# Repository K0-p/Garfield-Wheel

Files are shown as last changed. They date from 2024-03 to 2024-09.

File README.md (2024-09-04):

# Garfield Wheel

### HID-compliant (and Garfield-themed) game controller with embedded button mapping firmware and gyroscope controls
###### *Designed to run on the TM4C*

Developed by Gabriel Moore and Calvin Heischman

[Spring 2024 finalist for ECE445L at UT Austin](https://github.com/ECE445L/ECE445L-Winners/tree/main)

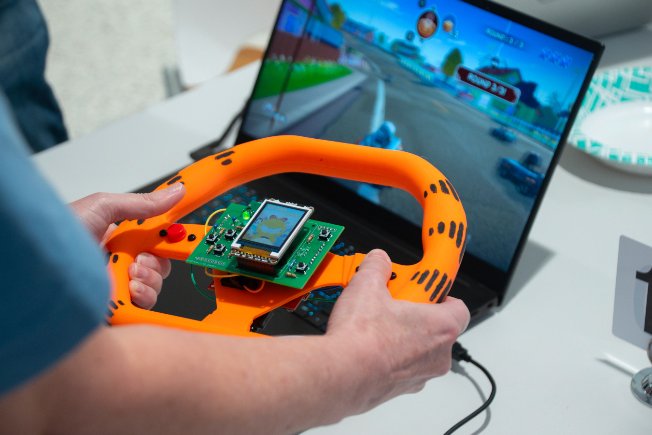
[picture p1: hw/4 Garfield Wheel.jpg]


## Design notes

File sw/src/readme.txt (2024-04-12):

USB HID Garfield Device
authors: Gabriel Moore and Calvin Heischman
*note: doesn't compile on uVision v5, get v4 ya dingus

This project is designed to run on the TM4C123GH6PM. It turns the device into a generic HID USB gamepad device.
Functionality:
	3-axis variable input
	8 buttons
	Can play Garfield Kart
	
Prototyped housing can be found in hw/wheel_models/

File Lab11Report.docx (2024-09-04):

Name: Calvin Heischman & Gabriel Moore

EID: CJH4858 & GAM3769

Semester: Spring 2024

Course: ECE445L

A) Objectives:

1. In a few sentences, describe the purpose of the lab and the features of your alarm clock.

This lab aims to build, test, and validate an embedded system. We created a gaming controller that is HID compliant thus allowing us to use it universally across several systems.

B) Hardware Design Deliverables:

1. N/A

C) Software Design Deliverables:

1. I have pushed my project to GitHub for grading (Yes/No):
2. Deliverable 1: System design diagram of the modules created.

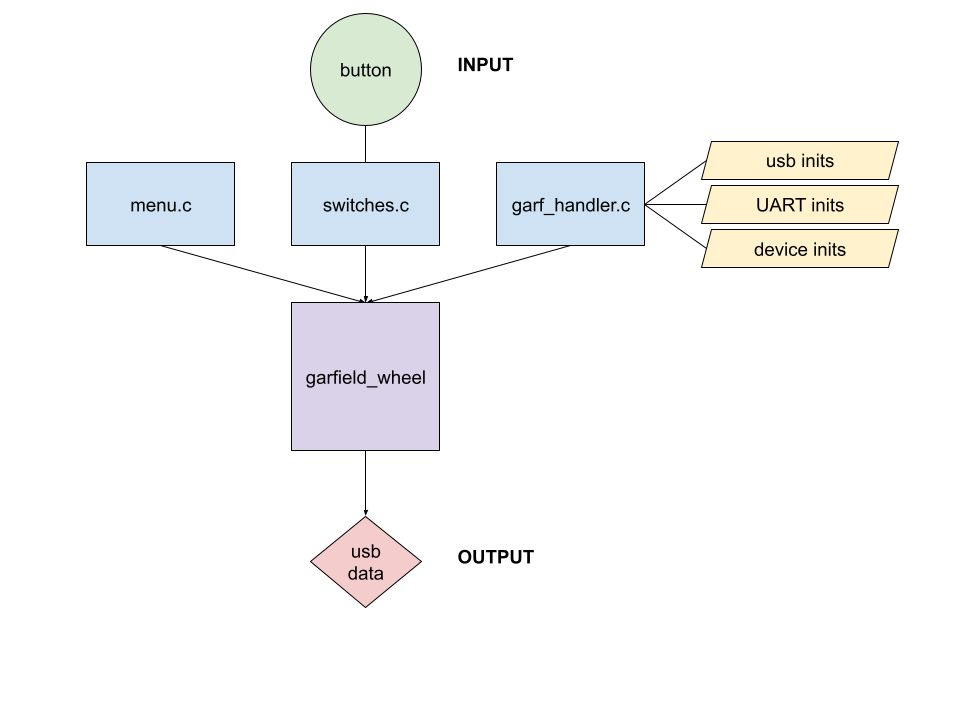
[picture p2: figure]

D) General Deliverables:

1. Deliverable 2: Software Tests

Button Publishing: When a button is pressed, the value is written both to the USB report and to a struct in the menu. If we want to verify that our button sampling is working properly, we can check either the usb report being sent (external) or print to the display to see what the tm4c is reading internally to make sure they match.

Device Descriptor: We define each entry in the string table, which combines to create the device descriptor. When the device is initialized, there is a verification function that checks if it was successfully received by the host before entering the main while loop. If we don’t properly describe the device, it will result in a specific fault at the main launch screen & we can check Wireshark to monitor the most recent data sent from the device to the host computer.

Menu functionality: We added multiple menu modes that change the button mappings in the HID report. This way, we’ve actually built our own debugging menu to configure the device based on specifications we need to test to compare both internal values with what gets sent to the external host.

2. Deliverable 3: Hardware Tests

Measured the current through several components to ensure they drew the right amount of power. Also checked for continuity throughout the systems to ensure that the current wasn’t being shorted anywhere in our circuit. Had components, like an LED that were used to quickly see if the board was being powered and if it had enough power to operate correctly.

3. Deliverable 4: Power consumption

25 + 160 + 3.6 + 25 + 7*2 = 227.6 mA (max current draw)

4. Deliverable 5 (10pt EC): Characterization of the system

CPU utilization: We performed this measurement by sampling the time different before and after each module execution. This execution time was then taken as a ratio of the overall bus frequency (50 Mhz). All of the following measurements met our system requirements as they were nonintrusive. The primary source of error stems from frequency of execution, as the following threads assume that each module is executed on every check instead of the cases where they are not.

    1. Thread 1 (garf handler): The handler is only used to initialize everything. This means it is called whenever the device is plugged/unplugged into the computer. When in the handler, it’s using 100% of the CPU since it disables all interrupts. But it’s only called once, so after initialization, it’s negligible and functionally 0% of overall CPU usage.
    2. Thread 2 (buttons): 0.0125%
    3. Thread 3 (menu): 0.0125% when inactive, 0.0347% when active

ADC jitter: 1.17 us. We performed this measurement by taking multiple before/after timestamps when we sampled the button polling and comparing the time the polls took. This met our system requirements as the time it took to sample was nonintrusive and therefore didn’t interrupt our ability to frequently poll the usb host. We might have experienced error from the number of buttons pressed, as we poll all the buttons but interrupt based on which ones get toggled.

E) Analysis and Discussion Questions:

1. N/A

Lab 6 report ECE445L

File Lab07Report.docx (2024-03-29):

Name: __Gabriel Moore and Calvin Heischman

EID: __GAM3769 and CJH4858

Semester: Spring 2024

Course: ECE445L

A) Objectives:

1. In a few sentences, describe the purpose of the lab:

The goal of this lab is to create a plan for the final project. That includes creating a proposal and requirements document for our systems, designing our system at the schematic level, implementing low-level software for our system, and demonstrating that the project is feasible.

B) Hardware Design Deliverables:

1. Deliverable 1: Using KiCad, create a schematic for your design. Include a screenshot in the space below.

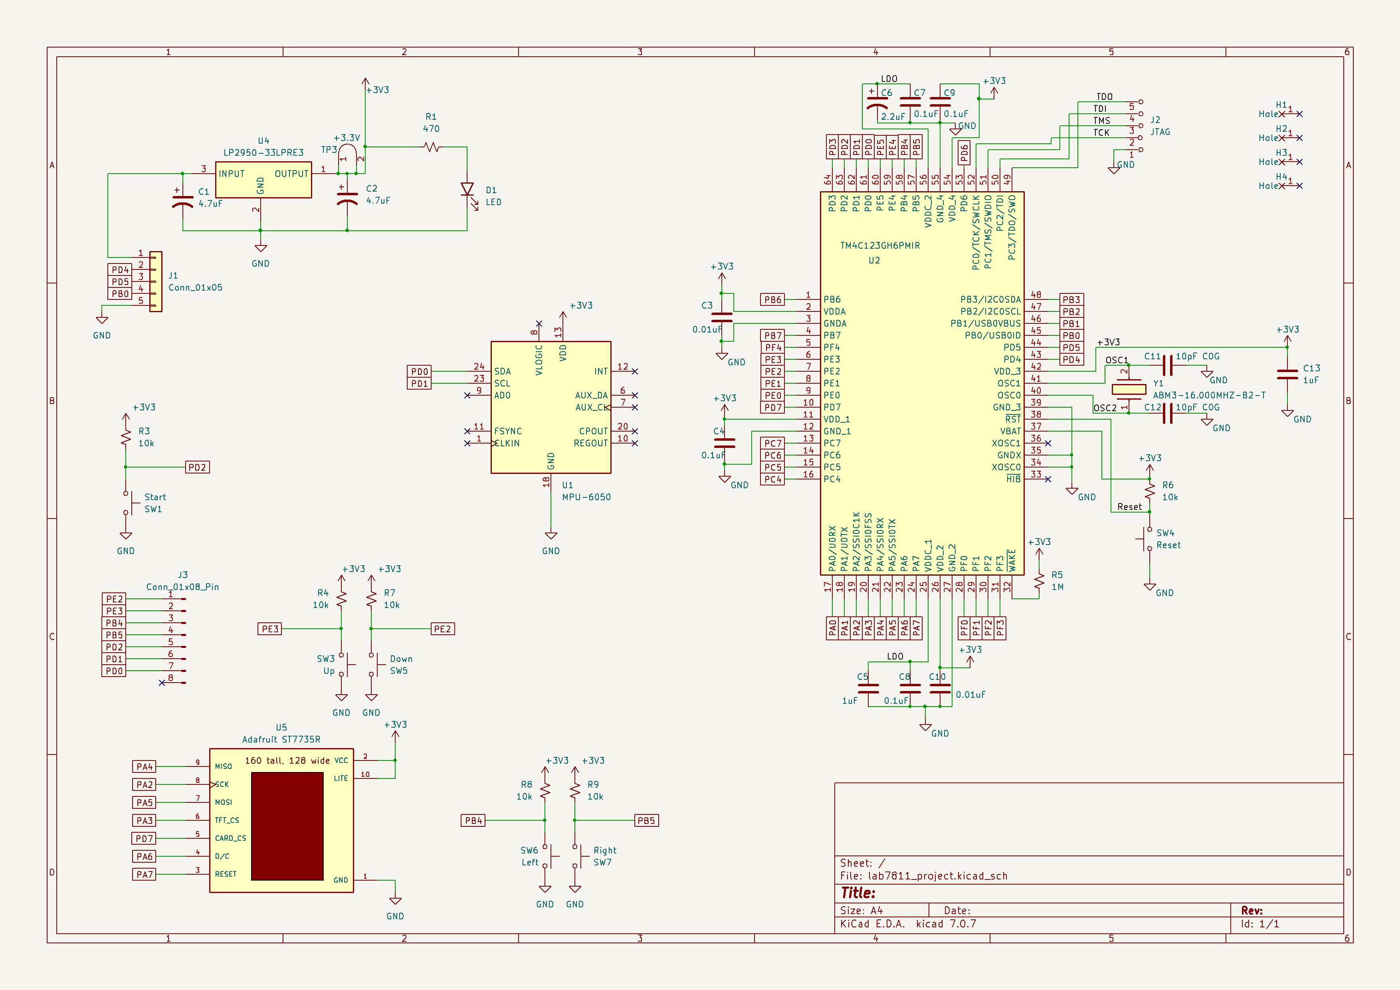
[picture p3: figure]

2. Deliverable 2: Using KiCad, create a Layout for your design. Include a screenshot in the space below.

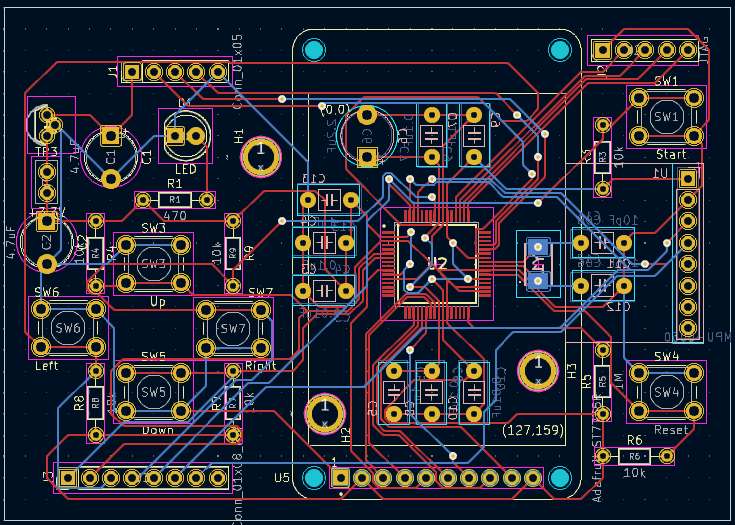
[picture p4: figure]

C) Software Design Deliverables:

1. I have pushed my project to GitHub for grading (Yes/No): Yes
2. Deliverable 3: System design diagram of the modules created.

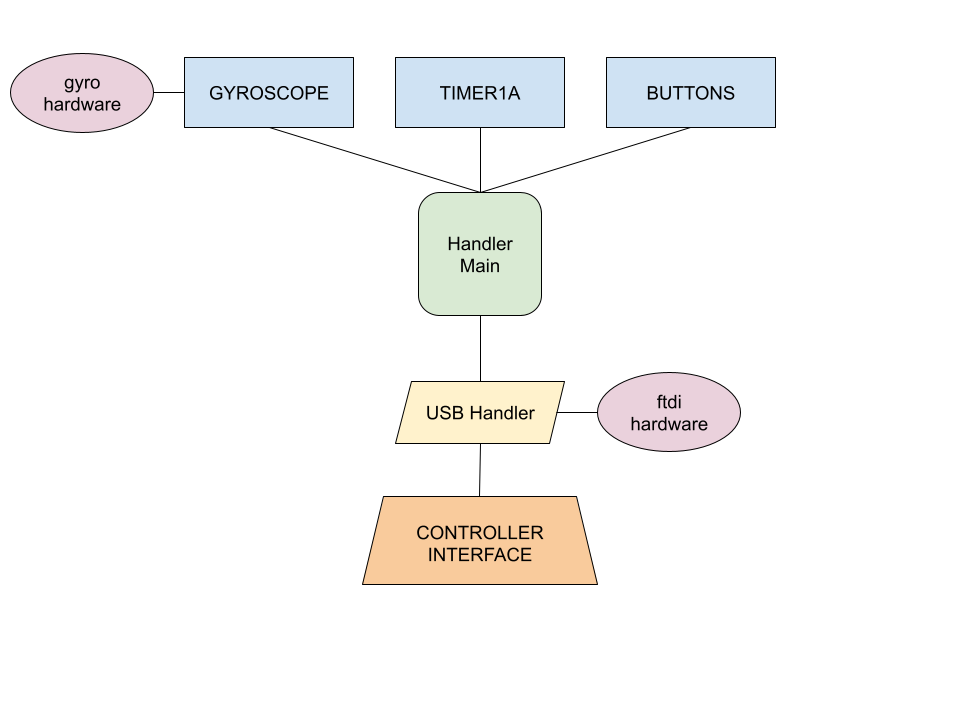
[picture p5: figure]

D) Deliverables:

1. Deliverable 4: Total cost estimate

I have updated the bill of materials (Yes/No): Yes

Out of pocket costs: $36.76

Adjusted competition costs: $24.33

2. Deliverable 5: Estimated current usage

25 + 160 + 3.6 + 25 + 7*2 = 227.6 mA (max current draw)

3. Deliverable 6 (5pt EC): TIW Training

Completed P1P TIW Training for the 3D printers (Gabriel Moore)

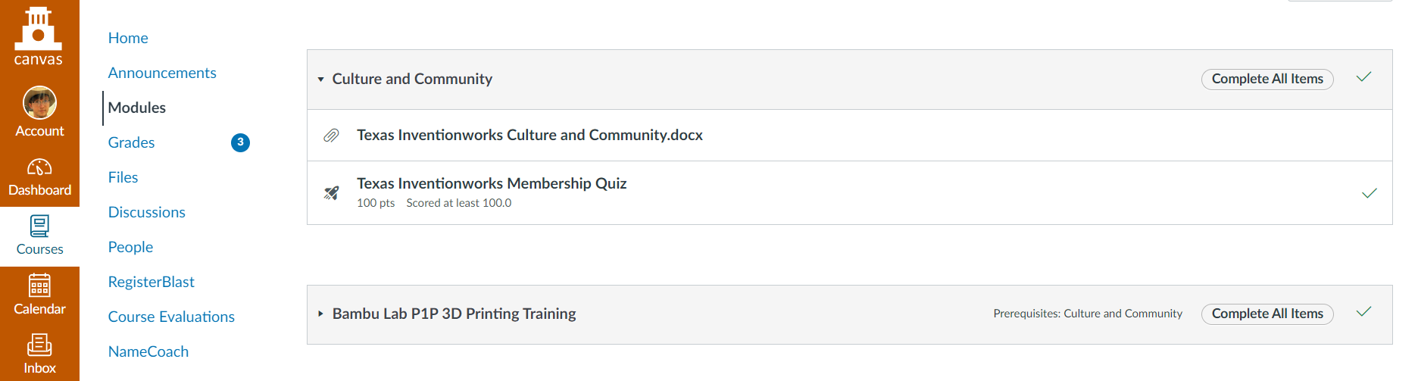
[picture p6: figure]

4. Deliverable 7 (10pt EC): Discrete IC usage

YES: (check PCB for details)

5. Deliverable 8 (10pt EC): Characterization of the system

E) Analysis and Discussion Questions:

1. How did you debug your system? How intrusive was it?

As of right now, we haven’t been able to debug our system as we weren’t able to order our parts until recently. We couldn’t join a group since all groups were filled, so now we’re doing the project as a 2-man group.

2. What’s the difference between unit testing, integration testing, and functional testing?
  a. Unit testing: is when you test individual sections/modules of your SW to ensure that they are performing correctly.
  b. Integration testing: this is when you combine and test the individual sections/modules of SW to ensure that they interact with each other as expected.
  c. Functional testing: is when you test the I/O of the SW by examining the output of the device based on different inputs.

Lab 7 report ECE445L

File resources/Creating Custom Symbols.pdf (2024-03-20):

## Creating Custom Symbols

## Contents

Creating Custom Symbols | 1

Introduction

KiCad is a powerful open-source software suite for electronic design automation (EDA). It offers a comprehensive set of tools for schematic capture and PCB layout. While KiCad comes with an extensive library of symbols and footprints, there are times when you may need to create custom symbols and footprints to suit specific components or devices not available in the standard libraries or online.

Creating custom symbols allows you to represent components accurately in your schematics, while custom footprints enable precise placement and routing of PCB components.

Creating a Custom Symbol

A symbol in KiCad represents a component on your schematic. Every component on a schematic must be precisely represented to ensure the functionality and reliability of the final product. While KiCad offers a vast library of pre-made symbols, there are instances where designers encounter unique components or specialized devices not covered by the standard offerings.

To create a symbol, open the symbol editor.

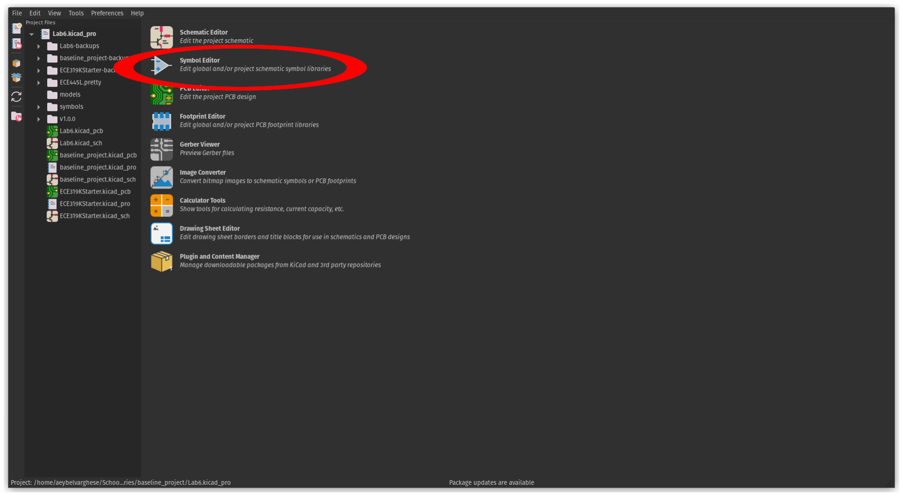
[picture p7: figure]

Figure 1: Main Menu

The KiCad Symbol Editor is a tool within the KiCad software suite specifically designed for creating and editing schematic symbols. It provides a user-friendly interface for designing graphical representations of electronic components, which are then used in schematics to illustrate circuit connections and layouts.

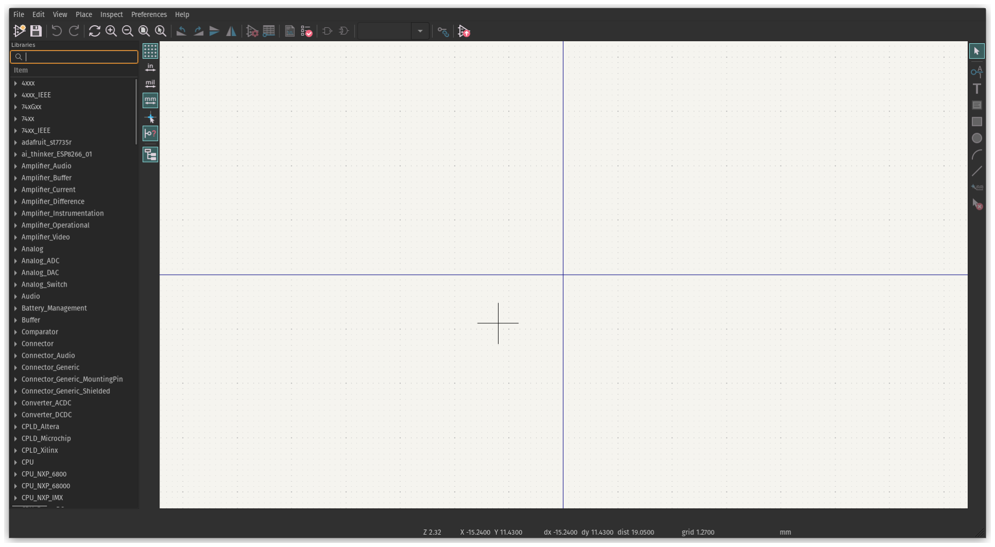
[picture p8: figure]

Figure 2: KiCad Symbol Editor

The Symbol Editor offers a graphical canvas where users can draw and manipulate schematic symbols using various drawing tools such as lines, arcs, polygons, and text boxes. The Symbol Editor allows users to save custom symbols to libraries for future use in other projects. Libraries can be organized and managed within KiCad to ensure easy access to custom symbols and efficient reuse across designs. Refer to the resource on adding libraries on more information regarding libraries.

When creating a symbol, it must be part of a library. We can either select a library to append a symbol to, or create a new library. To create a library, navigate to File → New Library, from here we can decide which symbol library table we want to add to, the global or project.

The global library table is shared amongst all your KiCad projects, while the project table is only for your currently open project. For this writeup, I am going to be adding it to the Project Table. When you press Ok, you can choose the location to save the “.kicad_sym” file which will contain your symbol library. You can choose any location you wish, although it is reccomended to have a folder dedicated for symbols organized in a reasonable matter. There is a “footprints” folder in the baseline project, and I will be storing the symbol library there. A entry in the symbol library table will be automatically made.

With a library selected in the left pane, press the “New Symbol Icon” or the Keyboard shortcut “N” to create a new symbol

Figure 3: Creating a symbol in the toolbar

Provide a name for the symbol, I am going to be creating a symbol for the MPU6050, (https://invensense.tdk.com/wp-content/uploads/2015/02/MPU-6000-Datasheet1.pdf) a IMU (Intertial Measurement Unit) from TDK InvenSense.

Creating symbols in KiCad involves designing graphical representations of electronic components to be used in schematics. Referring to datasheets during this process is crucial for accurately capturing the component’s electrical characteristics and pin configurations.

Referring to the pinout, we notice there are three categories of pins for this specific IC: power, communi-cation, and miscellaneous pins. We want to include all of these in our symbol. KiCad provides tools in the side toolbar to draw basic geometric shapes and describe pins.

Lets start by using the box tool to define the shape of our symbol.

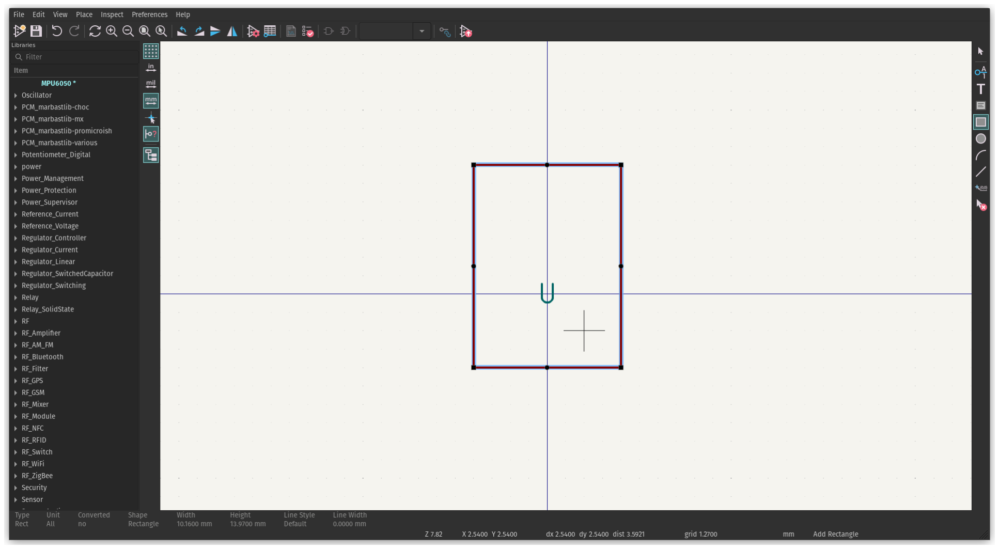
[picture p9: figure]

Figure 4: Box in Symbol Editor

With the shape of our pin assigned lets start adding pins. Select the “Add a Pin” button on the side toolbar, or press “P”.

When you press “Add a pin” in the KiCad Symbol Editor, you are prompted with several options to configure the properties of the pin being added to the symbol. These options allow you to define the electrical characteristics and behavior of the pin within the schematic symbol.

1. Name: This field allows you to specify the name of the pin, which is typically a descriptive label indicating the function or purpose of the pin within the component. Refer to the datasheet of the component for the name
2. Number: Here, you can assign a unique number to the pin. Pin numbers are used to identify individual pins within the symbol and are often based on the component’s datasheet or industry standards.
3. Orientation: This option determines the direction in which the pin is oriented within the symbol. You can choose from various orientations such as left, right, up, down.
4. Length: Specifies the length of the pin’s graphical representation within the symbol. This helps to visually distinguish pins of different lengths and aids in aligning pins with their corresponding connection points in the schematic.
5. Electrical Type: Defines the electrical characteristics of the pin, such as whether it is an input, output, bidirectional, power, or other special types. Selecting the appropriate electrical type ensures correct behavior during circuit simulation and layout as well as good for organization.
6. Visible: Determines whether the pin is visible or hidden in the symbol. Hidden pins are often used for internal connections or other purposes where the pin should not be displayed on the schematic.
7. Pin Function: This option allows you to specify additional information about the pin’s function or behavior, such as whether it is a clock input, reset signal, or other specialized function. This information aids in documentation and understanding the purpose of each pin within the symbol.

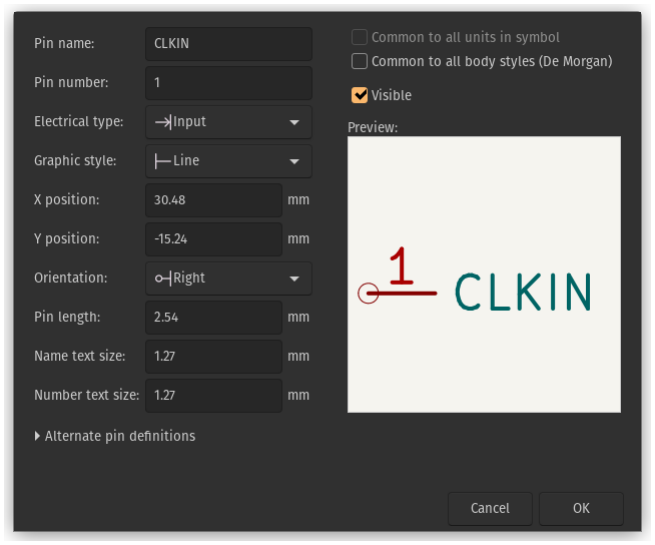
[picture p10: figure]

Figure 5: Describing a pin

Once we submit the options for the pin, we can place the pin down on our symbol.

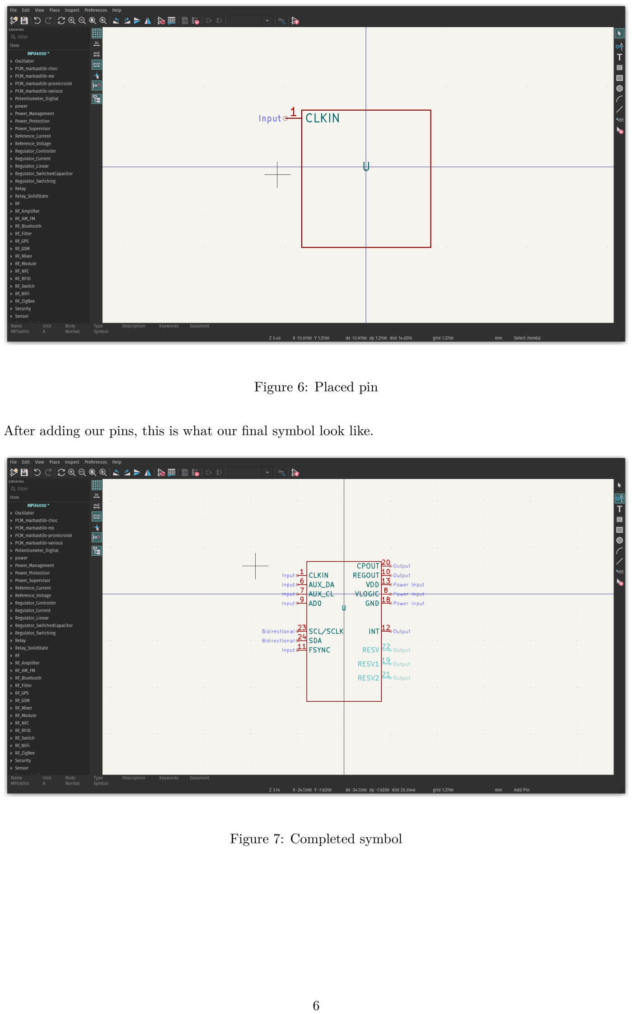
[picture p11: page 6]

Figure 6: Placed pin

After adding our pins, this is what our final symbol look like.

Figure 7: Completed symbol

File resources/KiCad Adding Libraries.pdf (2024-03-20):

## KiCAD - Adding Libraries to your project

## Contents

KiCAD - Adding Libraries to your project | 1

Introduction

In KiCAD (and any ECAD software), a symbol refers to a graphical representation of a component used in electronic circuit design. Symbols are used to represent various electronic components such as resistors, capacitors, integrated circuits, and more. Each symbol typically includes graphical elements that depict the component’s schematic representation, such as lines, shapes, and labels.

KiCad provides a library of pre-defined symbols for commonly used electronic components, and users can also create custom symbols as needed. Additionally, KiCad supports the import and export of symbol libraries in various formats, allowing users to share and reuse symbols across different projects and with other designers.

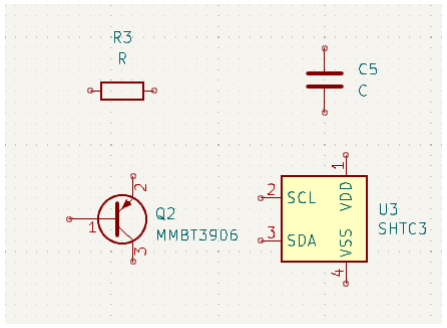
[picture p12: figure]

Figure 1: Symbols for a resistor, capacitor, BJT Transistor, and a SHTC3 Sensor

A footprint, refers to the physical layout or arrangement of metal pads, holes, and other features on a printed circuit board (PCB) that corresponds to a specific electronic component. The footprint represents the space and connection points required for soldering or mounting the component onto the PCB.

Footprints are crucial in the PCB design process as they ensure proper alignment, spacing, and connectivity of components on the board. Each electronic component, such as resistors, capacitors, integrated circuits, connectors, etc., typically has its own unique footprint that matches its physical dimensions and pin configuration.

Key elements of a footprint include:

- Pads: These are exposed metal areas on the PCB where components are typically soldered. Pads provide electrical connections between the component leads and the PCB traces. A component can be mounted either Through-hole (THT) or Surface mounted (SMD). In the case of Through-hole, the pins/leads of the component will go through the board; while the pins/leads of a SMD component sit on top of the pads on bottom or top surface of the board.
- Silkscreen Markings: These are non-conductive markings on the PCB that indicate component outlines, reference designators, polarity markings, or other important information to assist in assembly and troubleshooting.
- Keep-Out Areas: These are designated areas on the PCB where components or traces should not be placed to prevent interference or short circuits.

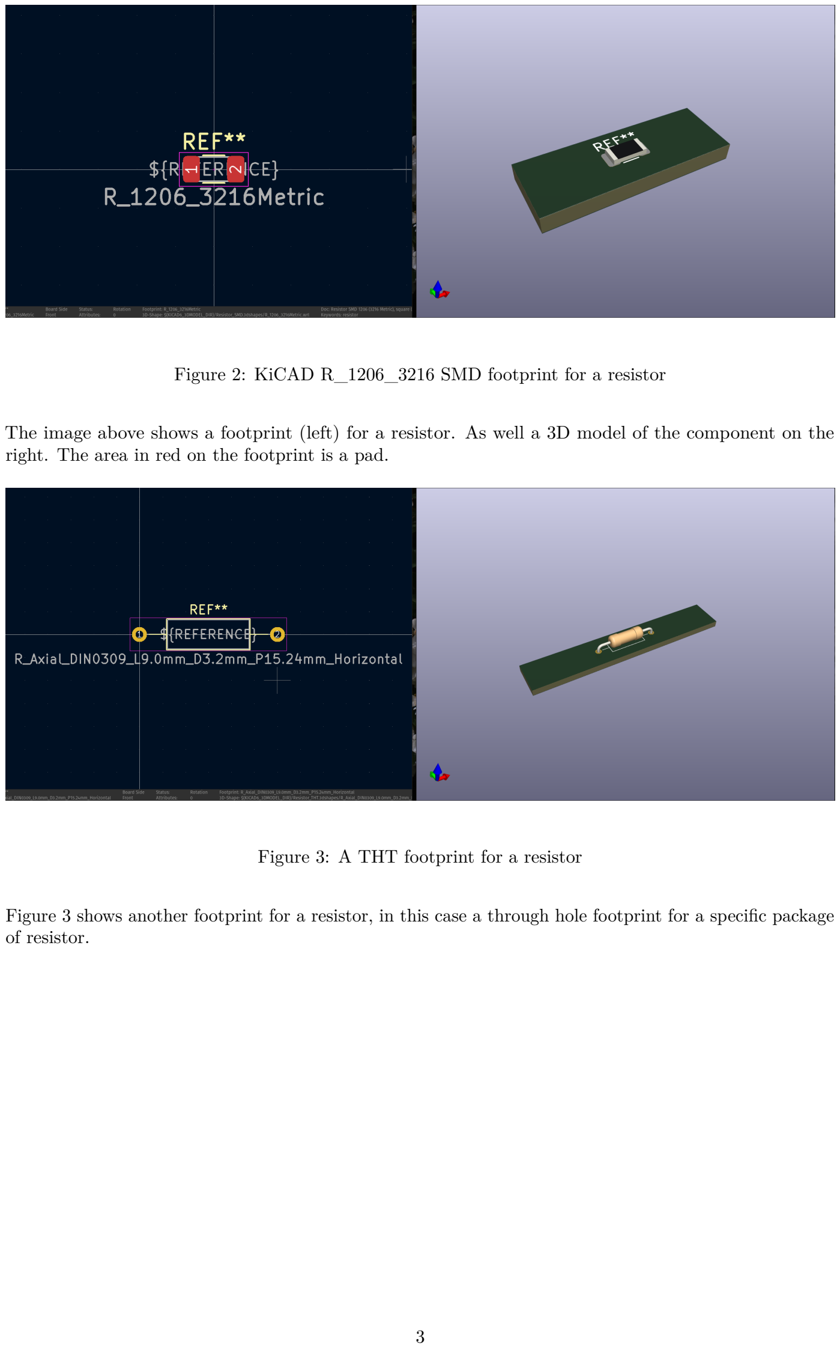
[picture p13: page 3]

Figure 2: KiCAD R_1206_3216 SMD footprint for a resistor

The image above shows a footprint (left) for a resistor. As well a 3D model of the component on the right. The area in red on the footprint is a pad.

Figure 3: A THT footprint for a resistor

Figure 3 shows another footprint for a resistor, in this case a through hole footprint for a specific package of resistor.

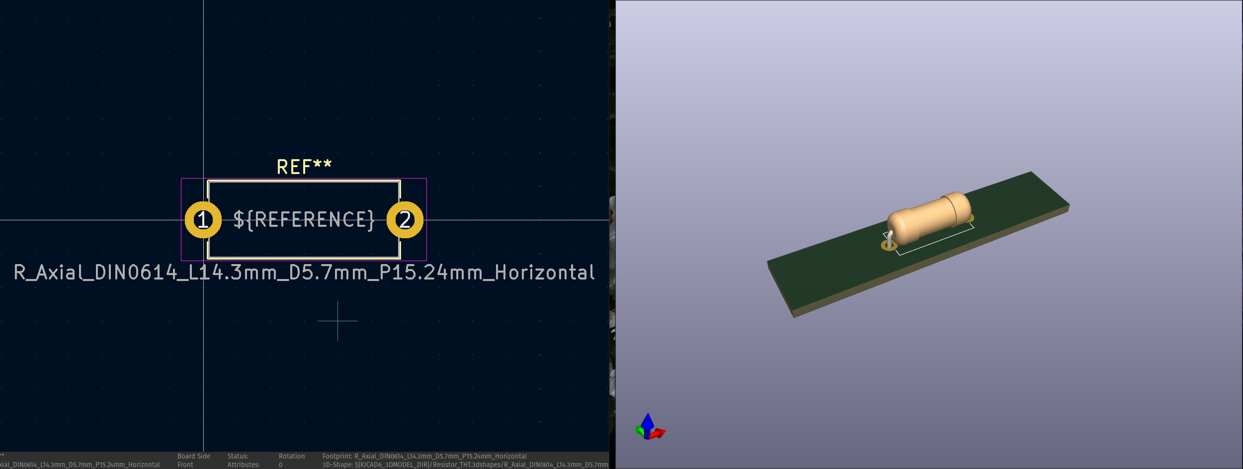
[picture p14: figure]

Figure 4: Another THT footprint for a resistor

If we were to look at the through-hole footprint in Figure 4, the yellow is pad which will be on the top and underside of the board. In all three of the footprints shown above, there is silkscreen. The silkscreen for this component is specified as "REF**" which is a special string that will get replaced with the value of the resistor on the schematic. On your PCB this value wil be visible on the silkscreen layer.

A package refers to the physical casing or enclosure that houses the semiconductor die or other active elements of the component. It provides mechanical support, protection, and electrical connections for the internal circuitry. Packages come in various shapes, sizes, and configurations depending on the type and application of the electronic component.

While both footprint and package relate to the physical aspects of electronic components, a footprint specifically refers to the layout on the PCB where the component will be mounted, while a package refers to the physical casing or enclosure of the electronic component itself.

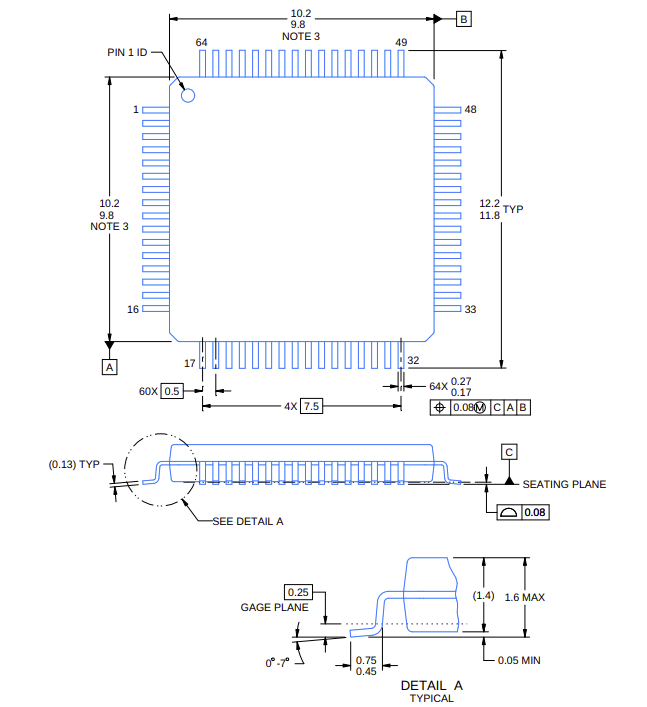
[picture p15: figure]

Figure 5: LQFP Package Outline of the TM4C123GH6PM

Finding Symbols and Footprints

There are a variety of ways of including symbols within your project. You can find them in these following sources

- Built-in Libraries: KiCad comes with a set of built-in libraries containing commonly used symbols and footprints. These libraries cover a wide range of electronic components. You can access these libraries directly within the KiCad software.
- Official KiCad Libraries: The KiCad project maintains official libraries that are regularly updated and expanded. These libraries contain a comprehensive collection of symbols and footprints for various components.
- Third-Party Libraries: There are many third-party libraries available online that provide additional symbols and footprints for KiCad. These libraries may cover specialized components or offer alternative options to the built-in libraries. You can find these libraries on websites such as GitHub, GitLab, or dedicated KiCad library repositories. With some installs of KiCAD, these libraries may already be installed alongside your KiCAD installation, these can be founde in the “3rdparty” folder of your KiCAD installation.
- Component Manufacturers and Vendors: Many component manufacturers provide down-loadable libraries containing symbols and footprints for their products. These libraries are often available on the manufacturer’s website and may include accurate and up-to-date models for their components. When sourcing components from vendors such as Mouser or Digikey, these vendors may have links to the symbols and footprints on their product page.
- Community Contributions: KiCad has a large and active community of users who contribute to the development of libraries. You can find user-contributed libraries, symbols, and footprints on forums, discussion boards, and community-driven websites. These contributions may cover a wide range of components and offer additional options for your designs.
- Creating Custom Symbols and Footprints: If you cannot find a specific symbol or footprint for your component, you can create custom ones using the KiCad footprint and symbol editors. This allows you to tailor the design to your exact specifications and requirements.

Different ECAD softwares such as Autodesk Eagle, Altium, KiCAD have different formats for symbols and libraries. As of the time of writing (Spring 2024) KiCAD 8 will be releasing soon, a major feature of this release includes the capability to import symbols from other software such as EAGLE.

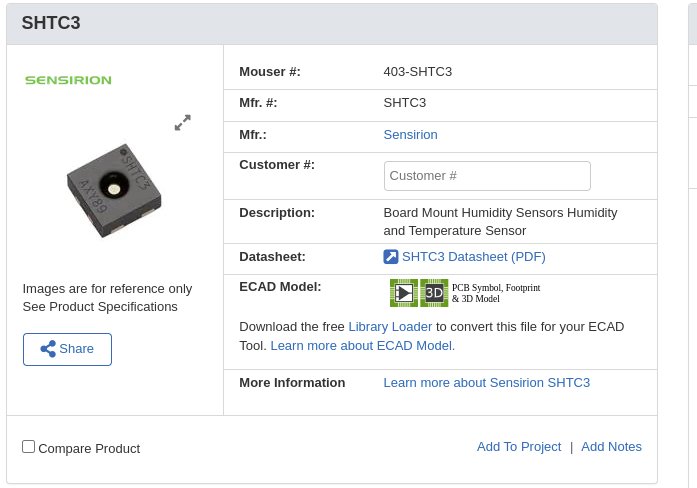
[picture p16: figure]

Figure 6: Link to Symbols and Footprints (ECAD Model) on Mouser Product Page

Services such as SnapEDA provide repositories to lookup symbols and footprints for components. These can be exported to a variety of ECAD software.

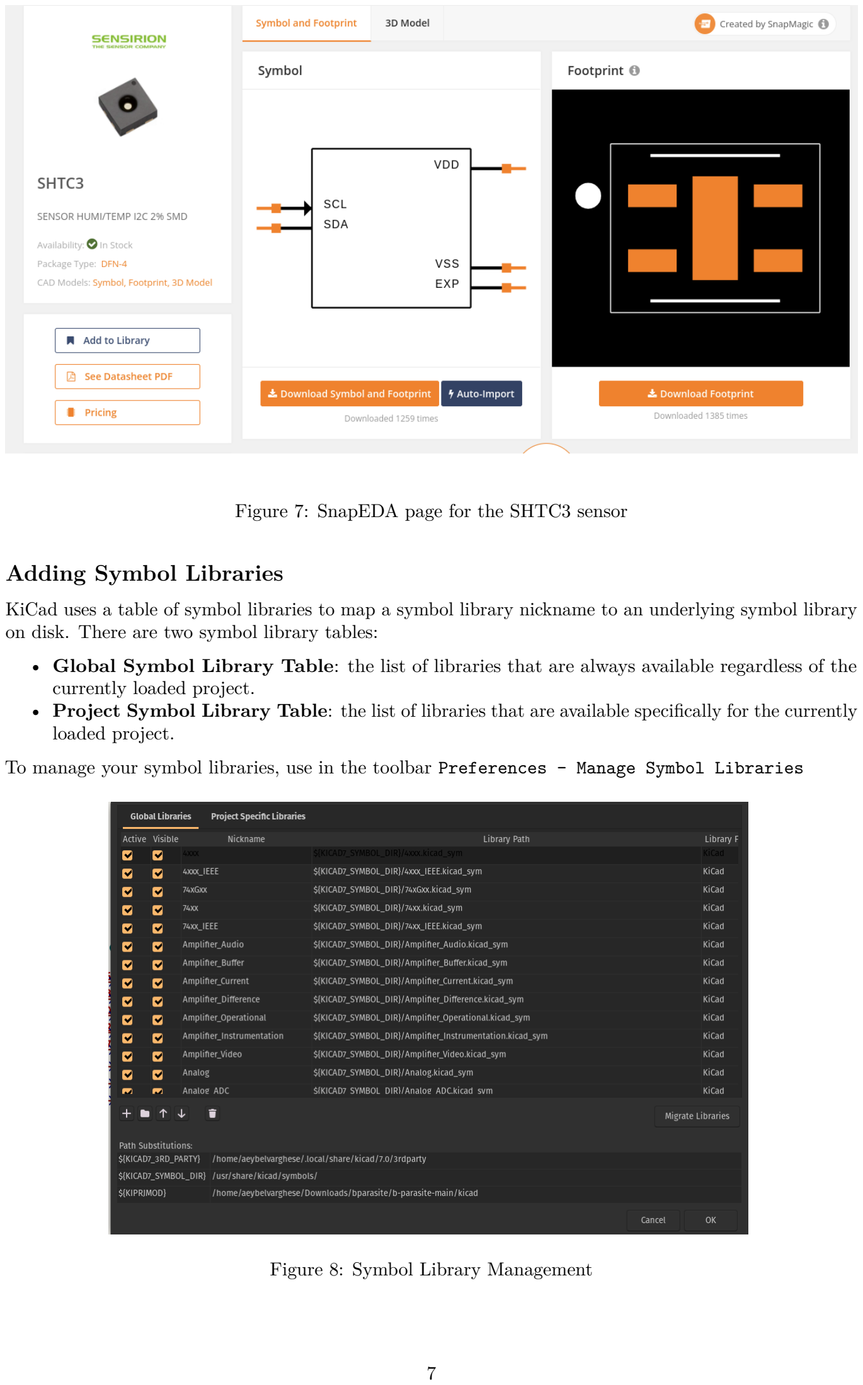
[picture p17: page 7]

Figure 7: SnapEDA page for the SHTC3 sensor

Adding Symbol Libraries

KiCad uses a table of symbol libraries to map a symbol library nickname to an underlying symbol library on disk. There are two symbol library tables:

- Global Symbol Library Table: the list of libraries that are always available regardless of the currently loaded project.
- Project Symbol Library Table: the list of libraries that are available specifically for the currently loaded project.

To manage your symbol libraries, use in the toolbar Preferences - Manage Symbol Libraries

Figure 8: Symbol Library Management

KiCAD Symbol libraries end with the extension .kicad_sym or .lib (legacy, comes bundled with footprints). When you download or create symbol libraries. It is a good idea to store the libraries in a reasonable location. For example, the ECE 445L symbols library would be best suited in a file location outside of inindividual lab projects. While project specific symbols are best suited within the project folder. Within the basline project we have a folder called symbols which contains project specific symbols, footprints which contains project specific footprints, and models which will contain 3D models for various footprints.

If we were too look at the symbols folder within the baseline project, we have symbols for the components we will be using within the lab such as for the ESP, TM4C, ST7735 Breakout board from Adafruit, etc.

Even if you download a symbol library, they can only be used if they have been added to either the global or project-specific symbol library table. You can add a entry to the table via the “+” button and typing the path, in this mode we can use path substitutions. Otherwise can can browse to the file using the file icon.

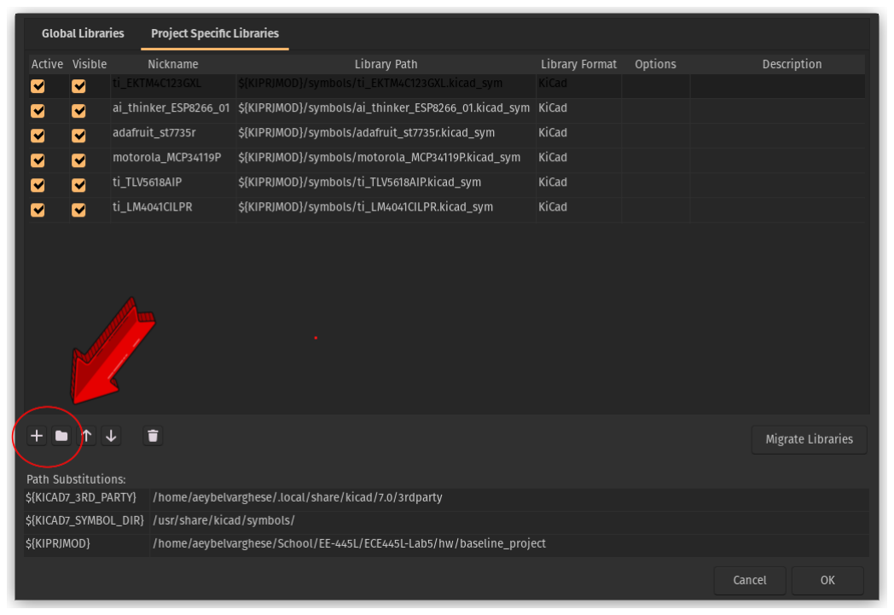
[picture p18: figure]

Figure 9: Adding entries to Symbol Table

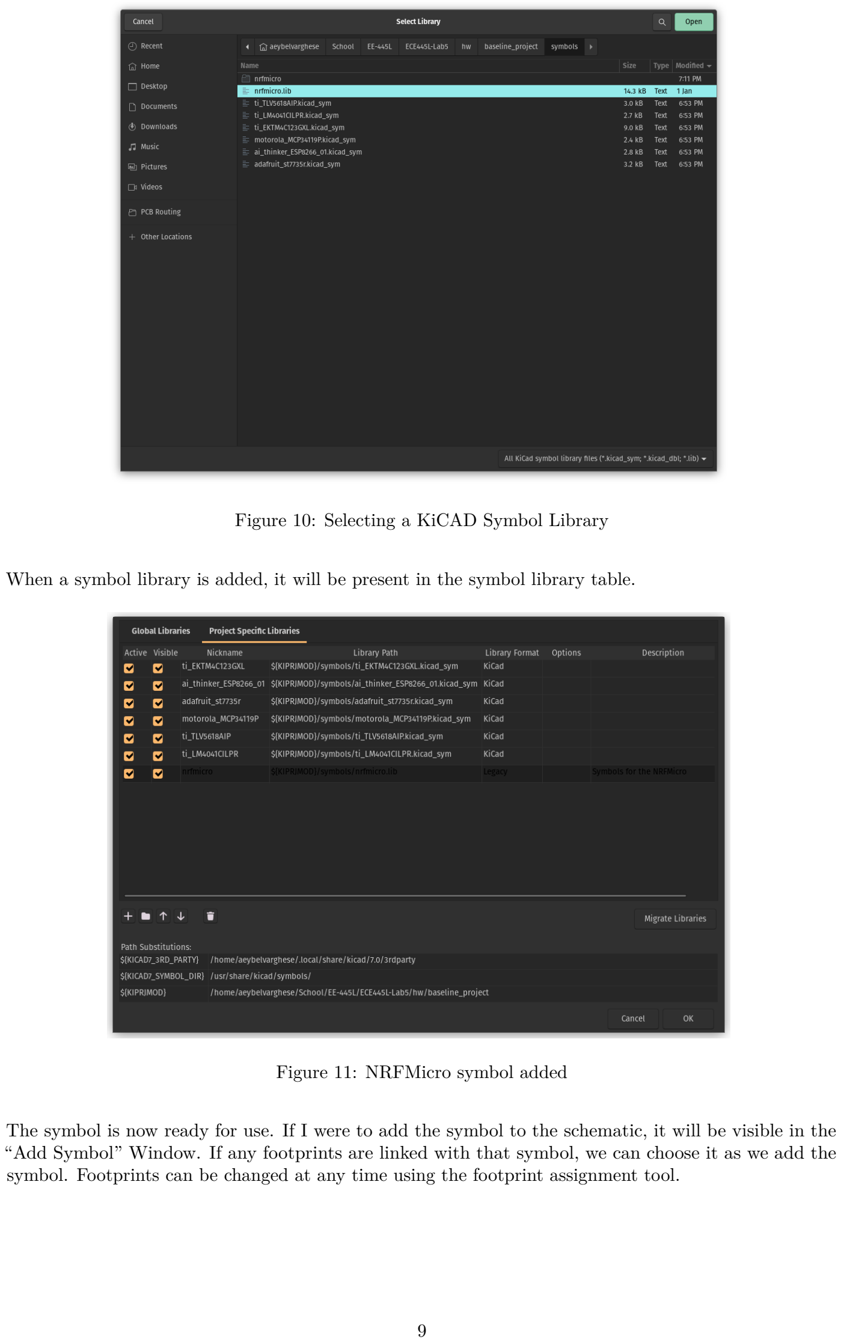
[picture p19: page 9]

Figure 10: Selecting a KiCAD Symbol Library

When a symbol library is added, it will be present in the symbol library table.

Figure 11: NRFMicro symbol added

The symbol is now ready for use. If I were to add the symbol to the schematic, it will be visible in the “Add Symbol” Window. If any footprints are linked with that symbol, we can choose it as we add the symbol. Footprints can be changed at any time using the footprint assignment tool.

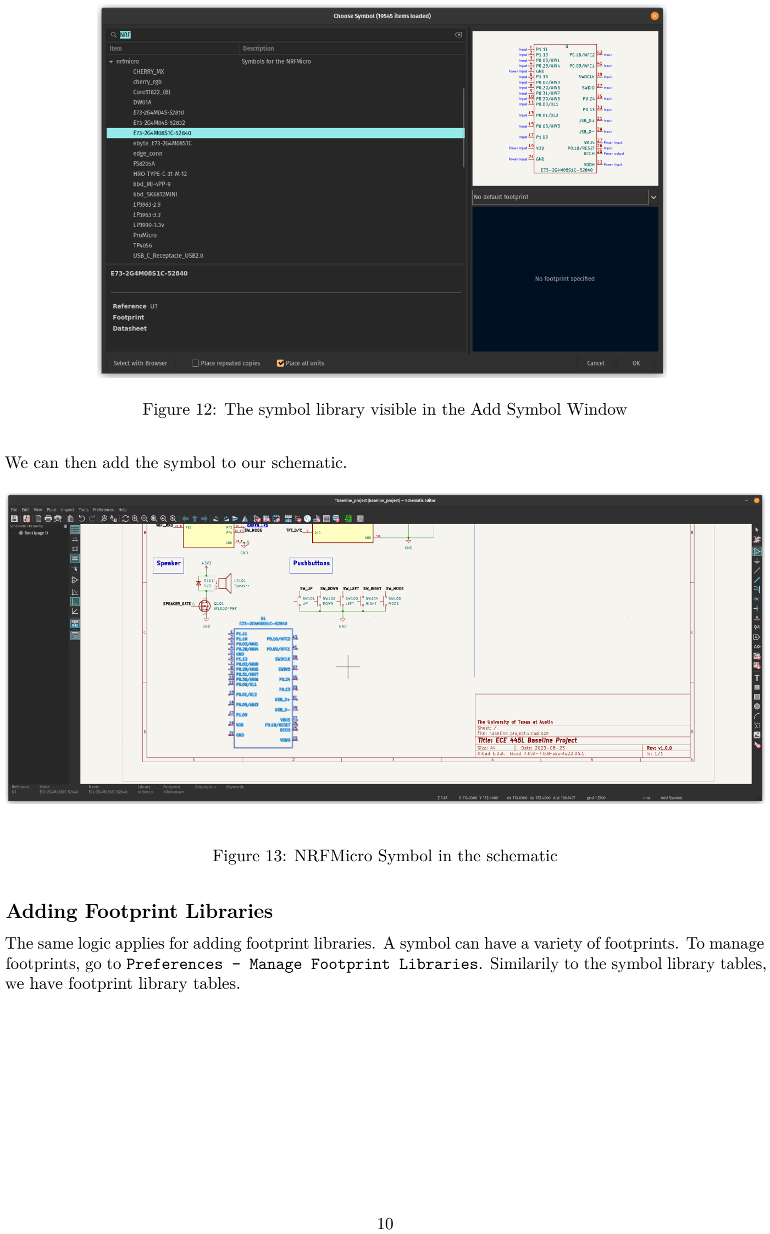
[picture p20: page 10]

Figure 12: The symbol library visible in the Add Symbol Window

We can then add the symbol to our schematic.

Figure 13: NRFMicro Symbol in the schematic

Adding Footprint Libraries

The same logic applies for adding footprint libraries. A symbol can have a variety of footprints. To manage footprints, go to Preferences - Manage Footprint Libraries. Similarily to the symbol library tables, we have footprint library tables.

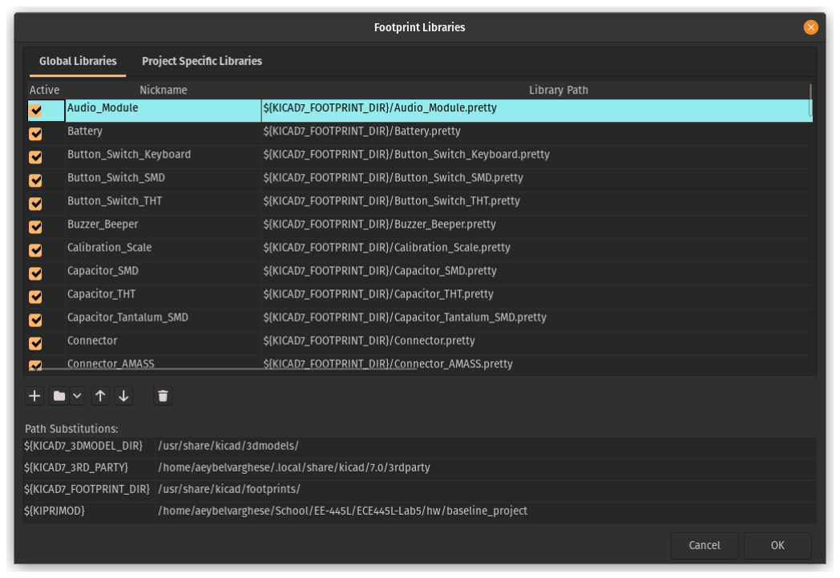
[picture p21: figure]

Figure 14: Footprint Library Management

We can add a entry to the table similarily to how we did in symbols, the only difference is that instead of having a entry pointing to a symbol file, for a footprint a entry points to the folder which contains the footprint. KiCAD footprints are stored as .kicad_mod files. In previous version of KiCAD, symbols and footprints would be bundled as .lib files.

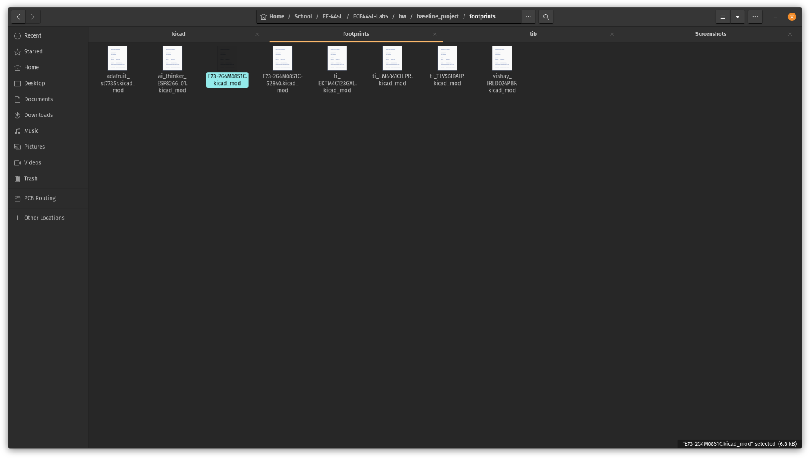
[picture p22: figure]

Figure 15: Footprint file for E73-2G4M08S1C within the footprints folder

In this case we had a entry for footprints, so I added the footprint for the NRFMicro to the footprints folder.

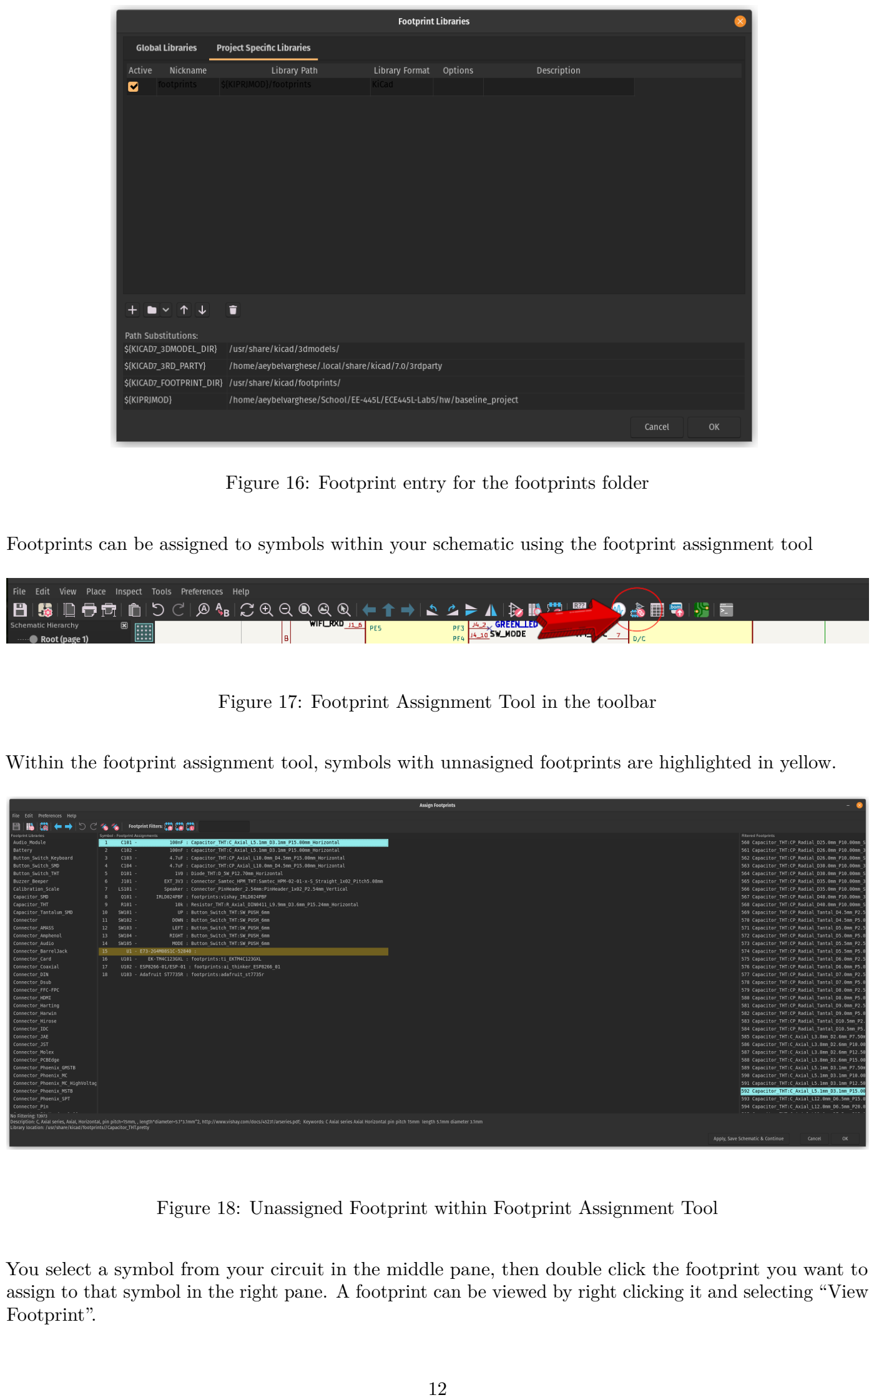
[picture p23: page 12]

Figure 16: Footprint entry for the footprints folder

Footprints can be assigned to symbols within your schematic using the footprint assignment tool

Figure 17: Footprint Assignment Tool in the toolbar

Within the footprint assignment tool, symbols with unnasigned footprints are highlighted in yellow.

Figure 18: Unassigned Footprint within Footprint Assignment Tool

You select a symbol from your circuit in the middle pane, then double click the footprint you want to assign to that symbol in the right pane. A footprint can be viewed by right clicking it and selecting “View Footprint”.

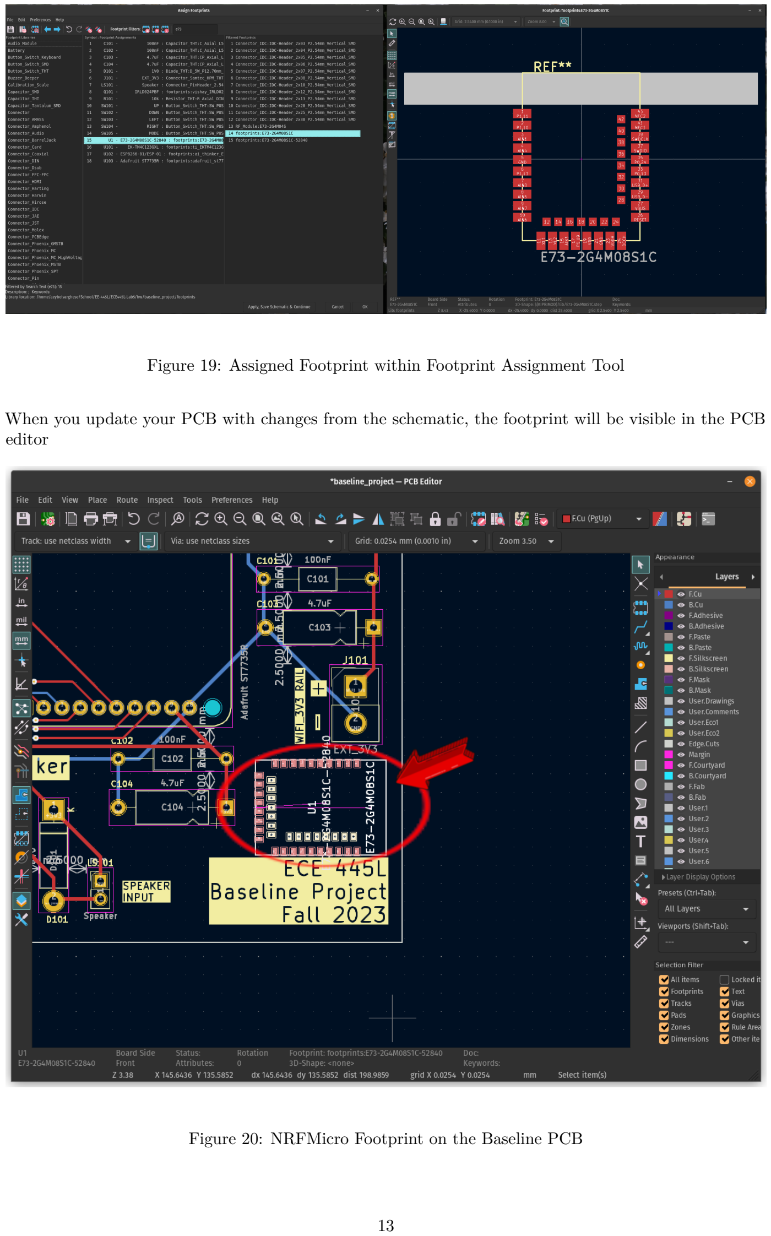
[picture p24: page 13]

Figure 19: Assigned Footprint within Footprint Assignment Tool

When you update your PCB with changes from the schematic, the footprint will be visible in the PCB editor

Figure 20: NRFMicro Footprint on the Baseline PCB

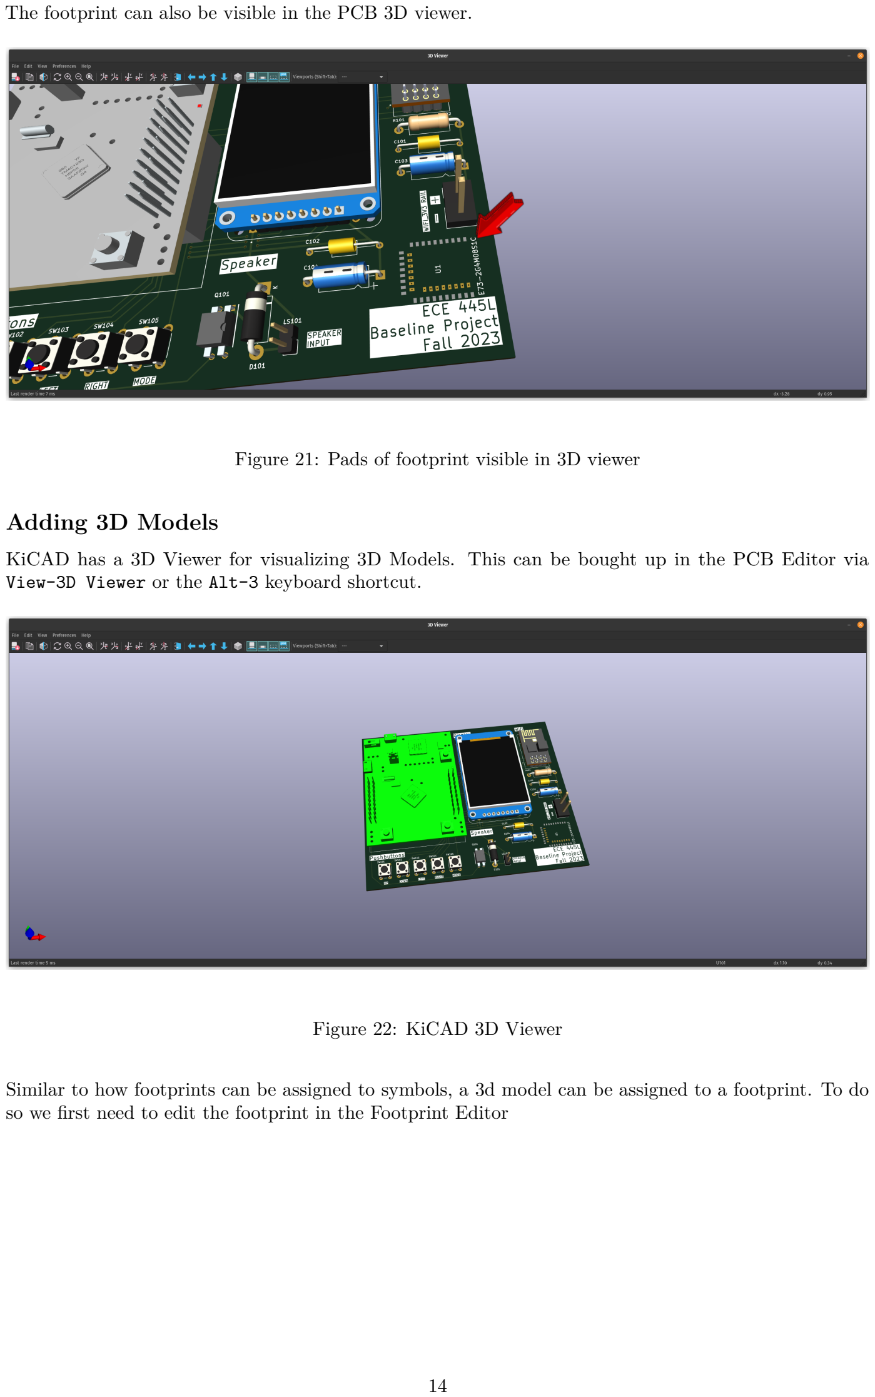
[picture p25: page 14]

The footprint can also be visible in the PCB 3D viewer.

Figure 21: Pads of footprint visible in 3D viewer

Adding 3D Models

KiCAD has a 3D Viewer for visualizing 3D Models. This can be bought up in the PCB Editor via View-3D Viewer or the Alt-3 keyboard shortcut.

Figure 22: KiCAD 3D Viewer

Similar to how footprints can be assigned to symbols, a 3d model can be assigned to a footprint. To do so we first need to edit the footprint in the Footprint Editor


Figure 23: Footprint Editor within Project Menu

Navigate to the footprint we want to edit.

Figure 24: Selected footprint in the editor

Select footprint properties within the toolbar.

Figure 25: Footprint editor toolbar


Figure 26: Footprint Properties

Within the footprint properties, we can see the 3d model(s) of the footprint. We can add one via the “+” button to add a path, or browse to it via the file icon. I use the file icon to navigate to the 3D Model of the component.


Figure 27: Selecting a 3D Model

Once a 3D Model has been imported, adjust parameters such as scale, rotation, and offset such that the components fits in the correct position.


Figure 28: Adjusting 3d model parameters

Once the footprint has a 3D model, update your PCB and you should now see the 3D model within the 3D viewer.


Figure 29: Full PCB 3D Model

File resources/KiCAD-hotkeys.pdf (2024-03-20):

### KiCAD Hotkeys

EESCHEMA | | PCBNEW
Help | ? | Switch Units | CTRL+U
Zoom In | F1 | Reset Local Coordinates | Space
Zoom Out | F2 | Undo | Ctrol+Z
Zoom Redraw | F3 | Redo | CTRL-Y
Zoom Center | F4 | Track Display Mode | K
Fit on Screen | Home | Delete | Del
Delete Item | Del | Delete Track Segment | BkSp
Repeat Lest Item | Ins | Add New Track | X
Move Block -> Drag Block | Tab | Add Via | V
Move Item | M | Add Microvia | CTRL+V
Copy Component or Label | C | Switch Track Posture | /
Drag Item | G | Drag Track, Keep Slope | D
Add Component | A | Place Item | P
Add Power | P | Copy Item | C
Rotate Item | R | End Track | End
Mirror X Component | X | Move Item | M
Mirror Y Component | Y | Flip Item | F
Orient Normal Component | N | Rotate Item | R
Edit Item | E | Drag Item | G
Edit Value | V | Get and Move Footprint | T
Edit Reference | U | Lock/Unlock Footprint | L
Edit Footprint | F | Save Board | Ctrl+S
Begin Wire | W | Load Board | Ctrol+L
Begin Bus | B | Find Item | Ctrl+F
End Line Wire Bus | K | Edit Item | End
Add Label | L | Switch to Cooper Layer | PgDn
Add Hierarchical Label | H | Switch to Inner Layer 1 | F5
Add Junction | J | Switch to Inner Layer 2 | F6
Add No Connect Flag | Q | Switch to Component Layer | PgUp
Add Sheet | S | Switch to Next Layer | +
Add Wire Entry | Z | Switch to Previous Layer | -
Add Bus Entry | / | Add Module | O
| | Switch Track Width to Next | W
| | Switch Track Width to Previous | Ctrl+W
| | Switch Highcontrast Mode | H
| | Invert (mirror) Block | Shift-LeftMouseB

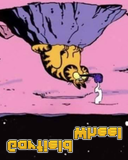
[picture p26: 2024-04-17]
sw/img/garf_pipe.png

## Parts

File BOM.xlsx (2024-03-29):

Bill of Materials
EE445L Spring 2022 | Fall 2023 |  |  | $42.66
Qty Note | REF DES Note (http://projects.ece.utexas.edu/valvano/wiki/doku.php?id=pcbartist:schematics)
Quantity | REF DES | Type | Est. Current (mA) | Description | Manufacturer | Mfg. P/N | Distributor | P/N | Unit cost | Cost | datasheet | Inventory
1 | TM4C123 chip | MCU | 25 | Texas Instruments TM4C123GH6PM Series ARM Microcontrollers MCU | Texas Instruments | TM4C123GH6PM | Mouser | 595-TM4C123GH6PMI | $12.50 | $12.50 |  | https://www.mouser.com/ProductDetail/Texas-Instruments/TM4C123GH6PMI?qs=9Y9qB%2FCsC3lZdfpeu9WHJw%3D%3D
1 | LDO regulator LP2950-33 | LDO | 160 | LP295x Adjustable Micropower Voltage Regulators with Shutdown | Texas Instruments | LP2950-33LPRE3 | Mouser | 595-LP2950-33LPRE3 | $0.64 | $0.64 |  | https://www.mouser.com/ProductDetail/Texas-Instruments/LP2950-33LPRE3?qs=iSMark9AYDUagDsOL8Eqdw%3D%3D
3 | Gyroscope MPU-6050 | GYRO | 3.6 | HiLetgo GY-521 MPU-6050 MPU6050 3 Axis Accelerometer Gyro | HiLetgo | B00LP25V1A | HiLetgo | MPU-6050 | $3.33 | $9.99 | https://invensense.tdk.com/wp-content/uploads/2015/02/MPU-6000-Datasheet1.pdf | https://www.amazon.com/HiLetgo-MPU-6050-Accelerometer-Gyroscope-Converter/dp/B00LP25V1A
1 | SH-U09C USB to TTL | FTDI | 25 | DSD TECH SH-U09C USB to TTL Serial Adapter with FTDI FT232RL | FTDI | 895-FT232RL | DSD Tech | FT232RL | $12.49 | $12.49 | https://ftdichip.com/wp-content/uploads/2020/08/DS_FT232R.pdf | https://www.amazon.com/DSD-TECH-Adapter-FT232RL-Compatible/dp/B07BBPX8B8
2 | Debug LED | LED | 7 | Standard LEDs - Through Hole Red Diffused 630nm 2.3mcd | Avago Technologies | HLMP-4700 | Mouser | 630-HLMP-4700 | $0.57 | $1.14 |  | https://www.mouser.com/ProductDetail/Broadcom-Avago/HLMP-4700?qs=jT9z6tsiFNlLY0m7YkBilg%3D%3D
10 | Micro USB to DIP | Adapter | n/a | HiLetgo Micro USB to DIP Adapter 5pin Female PCB Converter | HiLetgo | 2013499-1 | Mouser | 571-2013499-1 | $0.59 | $5.90 |  | https://www.mouser.com/ProductDetail/TE-Connectivity/2013499-1?qs=TL6PIybY3BOLK37GbUYdng%3D%3D
 |  |  |  |  |  |  |  |  |  |  |  |  | 5 CD
 |  |  |  |  |  |  |  |  |  |  |  | http://www.kemet.com/kemet/web/homepage/kechome.nsf/vapubfiles/F3101_GoldMax.pdf/$file/F3101_GoldMax.pdf

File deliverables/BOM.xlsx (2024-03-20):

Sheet: Parts
Bill of Materials |  |  | 2022-03-10 | "not free" means you have to buy it |  | "free sample" means you have to order it
EE445L Spring 2022 |  |  | EE445L pays for the PCB | "Cabinet means in one of the six black cabinets in professsor's office (bring a print out of your SCH")
 |  |  |  | "Professor" means ask your professor quantity and style will vary (bring a print out of your SCH circuit)
Qty Note | REF DES Note (http://projects.ece.utexas.edu/valvano/wiki/doku.php?id=pcbartist:schematics) |  |  | "Box means in box in your professor's office (bring a print out of your SCH circuit)
Quantity | REF DES | Type | Description | Manufacturer | Mfg. P/N | Distributor | P/N | Unit cost | Cost |  | Where to get it? | Inventory
0 |  | ASM | 8-ohm speaker |  |  | AllElectronics | SK-840 | $0.60 | $0.00 | Speaker | professor | https://www.allelectronics.com/item/sk-840/speaker-8-ohm-40mm/1.html
0 |  | ASM | 9V battery snap, T-type |  |  | AllElectronics | BST-61 | $0.50 | $0.00 | Jumper2 | Box
0 |  | ASM | Black case, 5.5" x 2.6" x 1.1" | Hammond | 1593YALBK | Mouser | 546-1593YALBK | $8.50 | $0.00 |  |  | http://www.hammondmfg.com/pdf/1593Y.pdf
0 |  | ASM | Black Case 5.620" x 3.250" X 1.500" | Serpac | 151 | Digikey | SR151B-ND | $10.88 | $0.00 |  | professor
0 |  | ASM | Black case, 7.5" by 4.3" by 2.2" | Hammond | 1591ESBK | Mouser | 546-1591ES-BK | $8.71 | $0.00 |  | Box | http://www.hammondmfg.com/pdf/1591E.pdf
0 |  | ASM | Electret microphone | Panasonic |  | AllElectronics | MIKE-79 | $0.50 | $0.00 | electret | Cabinet
0 |  | CAP | Ceramic, X7R, 20%, 1 uF |  |  | Jameco | 81509 | $0.35 | $0.00 | Ceramic0.2 | Cabinet
0 |  | CAP | Ceramic, Z5U, -20/+80%, 0.47 uF | Kemet | C320C474M5U5TA | Digikey | 399-4309-ND | $0.40 | $0.00 | Ceramic | Cabinet
0 |  | CAP | Ceramic, Z5U, -20/+80%, 0.1 uF |  |  | Digikey | 399-4151-ND | $0.04 | $0.00 | Ceramic | Cabinet
0 |  | CAP | Ceramic, Z5U, -20/+80%, 0.033 uF |  |  | Digikey | 399-4298-ND | $0.40 | $0.00 | Ceramic | Cabinet
0 |  | CAP | Ceramic, Z5U, -20/+80%, 0.027uF |  |  |  |  | $0.40 | $0.00 | Ceramic | Cabinet
0 |  | CAP | Ceramic, Z5U, -20/+80%, 0.01 uF |  |  | Digikey | 399-4148-ND | $0.40 | $0.00 | Ceramic | Cabinet
0 |  | CAP | Ceramic, Z5U, -20/+80%, 4.7 nF |  |  | Digikey | 399-4188-ND | $0.40 | $0.00 | Ceramic | Cabinet
0 |  | CAP | Ceramic, Z5U, -20/+80%, 2.2 nF |  |  |  |  | $0.40 | $0.00 | Ceramic | Cabinet
0 |  | CAP | Ceramic, Z5U, -20/+80%, 1 nF |  |  |  |  | $0.40 | $0.00 | Ceramic | Cabinet
0 |  | CAP | Ceramic Z5U, -20/+80%, 470 pF |  |  |  |  | $0.03 | $0.00 | Ceramic | Cabinet
0 |  | CAP | Ceramic Z5U, -20/+80%, 330 pF |  |  |  |  | $0.03 | $0.00 | Ceramic | Cabinet
0 |  | CAP | Ceramic Z5U, -20/+80%, 220 pF |  |  |  |  | $0.03 | $0.00 | Ceramic | Cabinet
0 |  | CAP | Ceramic Z5U, -20/+80%, 100 pF |  |  |  |  | $0.03 | $0.00 | Ceramic | Cabinet
0 |  | CAP | Ceramic Z5U, -20/+80%, 22 pF |  |  |  |  | $0.03 | $0.00 | Ceramic | Cabinet
0 |  | CAP | Ceramic C0G, 10%, 10 pF | Murata 50V 5% | RDE5C1H100J0P1H03B | Digikey | 490-8629-ND | $0.31 | $0.00 | Ceramic | Cabinet | not required, we expect most students will create a system with the LaunchPad
0 |  | CAP-Tant | Tantalum, 16V, 20% 2.2 uF | AVX Corporation | TAP225M016CCS | Digikey | 478-8819-ND | $0.29 | $0.00 | tantalum | Cabinet
0 |  | CAP-Tant | Tantalum, 16V, 10% 4.7 uF |  |  | Digikey | 478-1904-ND | $0.22 | $0.00 | tantalum | Cabinet
0 |  | CAP-Tant | Tantalum, 20V, 10%, 1 uF |  |  | Digikey | 478-1833-ND | $0.32 | $0.00 | tantalum | Cabinet
0 |  | CAP-Tant | Tantalum, 20V 10%, 10uF |  |  | Digikey | 478-1840-ND | $0.56 | $0.00 | tantalum | Cabinet
0 |  | CAP-Tant | Tantalum, 35V, 10%, 0.47 uF |  |  | Jameco | 33531 | $0.19 | $0.00 | tantalum | Cabinet
0 |  | CAP-Elec | Electrolytic, 16V, 100 uF, cap 20%, ESR=20mV |  |  | Mouser | 661-APSF160E101MF05S | $0.38 | $0.00 | tantalum | Cabinet
0 |  | CON | 2 to 40 pin 0.1 in header (price per pin) |  |  | AllElectronics | SHS-40 | $0.02 | $0.00 | Jumper2 | Cabinet | https://www.allelectronics.com/item/shs-40/1-x-40-header-0.1-spacing/1.html
0 |  | CON | 2-pin shrouded header (mates with SBC-2) |  |  | AllElectronics | SBH-2 | $0.10 | $0.00 | Jumper2 | Cabinet | https://www.allelectronics.com/item/sbh-2/header-for-small-battery-conn-2.5mm-spacing/1.html
0 |  | CON | 2-pin battery cable (mates with SBH-2) |  |  | AllElectronics | SBC-2 | $0.27 | $0.00 | goes with SBH-2 | Cabinet | https://www.allelectronics.com/item/sbc-2/small-battery-connector-2.5mm-spacing/1.html
0 |  | CON | 2-pin shorting jumper, attaches to 0.1" male-male header | Harwin | M7581-05 | Mouser | 855-M7581-05 | $0.11 | $0.00 | goes with Jumper2 | Cabinet
0 |  | CON | Test point, black | Keystone Electronics | 5001 | Digikey | 36-5001K-ND | $0.23 | $0.00 | testpoint | Cabinet
0 |  | CON | Test point, orange | Keystone Electronics | 5003 | Digikey | 36-5003K-ND | $0.23 | $0.00 | testpoint | Cabinet
0 |  | CON | Test point, yellow | Keystone Electronics | 5004 | Digikey | 36-5004K-ND | $0.23 | $0.00 | testpoint | Cabinet
0 |  | CON | Test point, white | Keystone Electronics | 5002 | Digikey | 36-5002K-ND | $0.23 | $0.00 | testpoint | Cabinet
0 |  | CON | Test point, blue | Keystone Electronics | 5117 | Digikey | 36-5117-ND | $0.23 | $0.00 | testpoint | Cabinet
0 |  | CON | Test point, green | Keystone Electronics | 5116 | Digikey | 36-5116-ND | $0.23 | $0.00 | testpoint | Cabinet
0 |  | CON | Test point, red | Keystone Electronics | 5000 | Digikey | 36-5000K-ND | $0.23 | $0.00 | testpoint | Cabinet
0 |  | CON | 10-pin female connector | SamTec | BCS-110-L-S-TE | Digikey | SAM1011-10-ND | $1.98 | $0.00 |  | Cabinet
0 |  | CON | Socket for micro SD card | Molex | 473340001 | Digikey | WM3288CT-ND | $4.02 | $0.00 | MicroSD Slot | Cabinet | do not use, rather included on ST7735
0 |  | CON | USB Mini-B socket, board mount, surface mount | Molex | 56579-0576 | Mouser | 538-56579-0576 | $2.46 | $0.00 | USB_Mini-B | Cabinet
0 |  | CON | Micro USB Type B, surface mount | Hirose Connector | ZX62D-B-5PA8(30) | Mouser | 798-ZX62D-B-5PA830 | $0.47 | $0.00 | USB_Micro-B | Cabinet
0 |  | CON | USB Mini-B socket, board mount, through hole | Molex | 54819-0519 | Digikey | WM17115-ND | $0.65 | $0.00 | USB_Mini-B | Cabinet
0 |  | CON | BoosterPack connector | FCI | 67996-220HLF | Mouser | 609-3243-ND | $0.26 | $0.00 | BoosterPack | Cabinet
0 |  | CON | Logic Analyzer connector | FCI | 68021-208HLF | Digikey | 609-3344-ND | $0.27 | $0.00 | LogicAnalyzer | Cabinet
0 |  | CON | JTAG 1 by 5 male header |  |  |  |  | $0.29 | $0.00 | JTAG | Cabinet
0 |  | CON | 10 pin 2mm socket for Xbee (need two) | SamTec | SQT-110-01-F-S | Digikey | SAM9989-ND | $2.70 | $0.00 | XbeeModule | Cabinet
0 |  | CPU | TM4C123GH6PM 64-pin LQFP | TI | TM4C123GH6PMI | Mouser | 595-TM4C123GH6PMI | $11.55 | $0.00 | TM4C123GH6PM |  | not required, we expect most students will create a system with the LaunchPad
0 |  | CRYS | NX5032GA-16.000000 | NDK | NX5032GA-16.000000 | Digikey | 644-1037-1-ND | $0.51 | $0.00 | XTAL/NX5032 | Cabinet | not required, we expect most students will create a system with the LaunchPad
0 |  | DIODE | 1N914 diode | Fairchild | 1N914 | Digikey | 1N914B-ND | $0.05 | $0.00 | 1N914 | Cabinet
0 |  | IC | LM2937 3.3 V regulator TO220, 500mA | TI | LM2937ET-3.3/NOPB | Digikey | LM2937ET-3.3-ND | $1.17 | $0.00 | LM2937-3.3 | Cabinet
0 |  | IC | LP2950 3.3V regulator, 100 mA TO-92 | TI | LP2950-33LPRE3 | Digikey | 296-31455-1-ND | $0.19 | $0.00 | LP2950-CZ-3.3 | Cabinet
0 |  | IC | 78M05 500mA 5V TO-220 regulator | National | LM78M05 | Jameco | 192233 | $0.19 | $0.00 | LM7805CT | Cabinet
0 |  | IC | OPA4350 quad op amp | TI | OPA4350UA | Mouser | 595-OPA4350UA | $12.15 | $0.00 | OPA4350 | not free
0 |  | IC | TLV5616 12-bit DAC | TI | TLV5616CP | Mouser | 595-TLV5616CP | $10.09 | $0.00 | TLV5616 | not free
0 |  | IC | TLV5618 dual 12-bit DAC | TI | TLV5618 | Mouser | TLV5618ACP | $14.18 | $0.00 | TLV5618 | not free
0 |  | IC | INA122P instrumentation amp | TI | INA122P | Mouser | 595-INA122P | $9.09 | $0.00 | INA122 | Cabinet or free sample
0 |  | IC | OPA2350 dual op amp | TI | OPA2350PA | obsolete |  |  | $0.00 | OPA2350 | Cabinet or free sample |  |  | 1 KD
0 |  | IC | TLC2274 quad op amp | TI | TLC2274ACN | Mouser | 595-TLC2274ACN | $3.06 | $0.00 | TLC2274 | not free |  |  | 2 HD
0 |  | IC | TPA731 audio amp (pin 1 low) 700mW | TI | TPA731D | Mouser | 595-TPA731D | $2.90 | $0.00 | TPA731 | not free |  |  | 3 AD
0 |  | IC | TPA751 audio amp (pin 1 high) 700mW | TI | TPA751D | Mouser | 595-TPA751D | $2.31 | $0.00 | TPA731 | not free |  |  | 4 JD
0 |  | IC | LM4041CILPR shunt diode reference | TI | LM4041CILPR | Mouser | 595-LM4041CILPR | $1.21 | $0.00 | LM4041 | Cabinet or free sample |  |  | 5 CD
0 |  | IC | L293 Motor H bridge | TI | L293NE | Digikey | 296-9519-5-ND | $3.50 | $0.00 | L293 | Cabinet |  |  | 7 MD
0 |  | IC | 74HC595 |  |  | Jameco | 46105 | $0.40 | $0.00 |  | Cabinet |  |  | 8 ED
0 |  | IC | 74HC165 |  |  | Jameco | 45495 | $0.30 | $0.00 |  | Cabinet |  |  | 9 FD
0 |  | IC | 74HCT125N | TI | SN74HCT125N | Mouser | 595-SN74HCT125N | $0.53 | $0.00 |  | Cabinet
0 |  | IC | RS232 driver | STMicroelectronics | ST232CN | Jameco | 2001171 | $0.58 | $0.00 | ST232 | Cabinet |  |  | 0 ND
0 |  | JACK | DC Power MALE 2.1mm |  |  | Jameco | 101179 | $0.55 | $0.00 | PowerJack | Cabinet |  |  | * LD
0 |  | JACK | Stereo Jack, or audio jack |  |  | AllElectronics | MJW-12 | $0.09 | $0.00 | HeadphoneJack | Cabinet |  | 87YY3212A
0 |  | KEY | 3 by 4 common bus (D), keypad | Grayhill | 87YY3212A-506 |  |  | $2.99 | $0.00 | 87YY3212A | Box | http://docs.bgmicro.com/pdf/swt1109.pdf
0 |  | LCD | 18-bit color 128*160 1.8" TFT LCD display | Sitronix | ST7735R | Adafruit | 358 | $19.96 | $0.00 | ST7735 | not free
0 |  | LED | Green 2mA 5mm diffused | Avago Technologies | HLMP-4740 | Digikey | 516-1327-ND | $0.29 | $0.00 | LEDT1.75 | Cabinet
0 |  | LED | Red 1.6V 1mA 5mm diffused | Avago Technologies | HLMP-D150 | Digikey | 516-1323-ND | $0.29 | $0.00 | LEDT1.75 | Cabinet
0 |  | LED | Yellow 2mA 5mm diffused | Avago Technologies | HLMP-4719 | Digikey | 516-1326-ND | $0.29 | $0.00 | LEDT1.75 | Cabinet
0 |  | LED | Orange 10mA 5mm diffused | Avago Technologies | HLMP-D401 | Digikey | 516-1330-ND | $0.29 | $0.00 | LEDT1.75 | Cabinet
0 |  | LED | Blue 10mA 5mm diffused |  |  |  |  | $0.99 | $0.00 | LEDT1.75 | Cabinet | warning, the blue LEDs are very bright
0 |  | PCB | PCB plus shipping | JLCPCB |  | JLCPCB |  | $13.00 | $0.00
0 |  | POT | 20K LINEAR SLIDE POT | Bourns | PTA2043-2015CPB103 | Mouser | 652-PTA20432015CPB10 | $1.28 | $0.00 |  | Cabinet
0 |  | POT | 10 K one-turn potentiometer |  |  |  |  | $0.15 | $0.00 | SquarePot | Professor
0 |  | POT | 20 K one-turn potentiometer |  |  |  |  | $0.15 | $0.00 | SquarePot | Professor
0 |  | RES | Carbon 1/6W, 5%, 100 | Yageo | CFR-12JB-100R | Digikey | 100EBK-ND | $0.02 | $0.00 | 0.125Wresistor | Cabinet
0 |  | RES | Carbon 1/6W, 5%, 220 | Yageo | CFR-12JB-220R | Digikey | 220EBK-ND | $0.02 | $0.00 | 0.125Wresistor | Cabinet
0 |  | RES | Carbon 1/6W, 5%, 270 | Yageo | CFR-12JB-270R | Digikey | 270EBK-ND | $0.02 | $0.00 | 0.125Wresistor | Cabinet
0 |  | RES | Carbon 1/6W, 5%, 330 | Yageo | CFR-12JB-330R | Digikey | 330EBK-ND | $0.02 | $0.00 | 0.125Wresistor | Cabinet
0 |  | RES | Carbon 1/6W, 5%, 470 | Yageo | CFR-12JB-470R | Digikey | 470EBK-ND | $0.02 | $0.00 | 0.125Wresistor | Cabinet
0 |  | RES | Carbon 1/6W, 5%, 510 | Yageo | CFR-12JB-510R | Digikey | 510EBK-ND | $0.02 | $0.00 | 0.125Wresistor | Cabinet
0 |  | RES | Carbon 1/6W, 5%, 680 | Yageo | CFR-12JB-680R | Digikey | 680EBK-ND | $0.02 | $0.00 | 0.125Wresistor | Cabinet
0 |  | RES | Carbon 1/6W, 5%, 820 | Yageo | CFR-12JB-820R | Digikey | 820EBK-ND | $0.02 | $0.00 | 0.125Wresistor | Cabinet
0 |  | RES | Carbon 1/6W, 5%, 1K | Yageo | CFR-12JB-1K0 | Digikey | 1.0KEBK-ND | $0.02 | $0.00 | 0.125Wresistor | Cabinet
0 |  | RES | Carbon 1/6W, 5%, 1.2K | Yageo | CFR-12JB-1K2 | Digikey | 1.2KEBK-ND | $0.02 | $0.00 | 0.125Wresistor | Cabinet
0 |  | RES | Carbon 1/6W, 5%, 1.5K | Yageo | CFR-12JB-1K5 | Digikey | 1.5KEBK-ND | $0.02 | $0.00 | 0.125Wresistor | Cabinet
0 |  | RES | Carbon 1/6W, 5%, 1.8K | Yageo | CFR-12JB-1K8 | Digikey | 1.8KEBK-ND | $0.02 | $0.00 | 0.125Wresistor | Cabinet
0 |  | RES | Carbon 1/6W, 5%, 2.0K | Yageo | CFR-12JB-2K0 | Digikey | 2.0KEBK-ND | $0.02 | $0.00 | 0.125Wresistor | Cabinet
0 |  | RES | Carbon 1/6W, 5%, 2.2K | Yageo | CFR-12JB-2K2 | Digikey | 2.2KEBK-ND | $0.02 | $0.00 | 0.125Wresistor | Cabinet
0 |  | RES | Carbon 1/6W, 5%, 2.7K | Yageo | CFR-12JB-2K7 | Digikey | 2.7KEBK-ND | $0.02 | $0.00 | 0.125Wresistor | Cabinet
0 |  | RES | Carbon 1/6W, 5%, 3.3K | Yageo | CFR-12JB-3K3 | Digikey | 3.3KEBK-ND | $0.02 | $0.00 | 0.125Wresistor | Cabinet
0 |  | RES | Carbon 1/6W, 5%, 3.9K | Yageo | CFR-12JB-3K9 | Digikey | 3.9KEBK-ND | $0.02 | $0.00 | 0.125Wresistor | Cabinet
0 |  | RES | Carbon 1/6W, 5%, 4.7K | Yageo | CFR-12JB-4K7 | Digikey | 4.7KEBK-ND | $0.02 | $0.00 | 0.125Wresistor | Cabinet
0 |  | RES | Carbon 1/6W, 5%, 5.1K | Yageo | CFR-12JB-5K1 | Digikey | 5.1KEBK-ND | $0.02 | $0.00 | 0.125Wresistor | Cabinet
0 |  | RES | Carbon 1/6W, 5%, 5.6K | Yageo | CFR-12JB-5K6 | Digikey | 5.6KEBK-ND | $0.02 | $0.00 | 0.125Wresistor | Cabinet
0 |  | RES | Carbon 1/6W, 5%, 6.8K | Yageo | CFR-12JB-6K8 | Digikey | 6.8KEBK-ND | $0.02 | $0.00 | 0.125Wresistor | Cabinet
0 |  | RES | Carbon 1/6W, 5%, 8.2K | Yageo | CFR-12JB-8K2 | Digikey | 8.2KEBK-ND | $0.02 | $0.00 | 0.125Wresistor | Cabinet
0 |  | RES | Carbon 1/6W, 5%, 10K | Yageo | CFR-12JB-10K | Digikey | 10KEBK-ND | $0.02 | $0.00 | 0.125Wresistor | Cabinet
0 |  | RES | Carbon 1/6W, 5%, 12K | Yageo | CFR-12JB-12K | Digikey | 12KEBK-ND | $0.02 | $0.00 | 0.125Wresistor | Cabinet
0 |  | RES | Carbon 1/6W, 5%, 15K | Yageo | CFR-12JB-15K | Digikey | 15KEBK-ND | $0.02 | $0.00 | 0.125Wresistor | Cabinet | http://www.kemet.com/kemet/web/homepage/kechome.nsf/vapubfiles/F3101_GoldMax.pdf/$file/F3101_GoldMax.pdf
0 |  | RES | Carbon 1/6W, 5%, 18K | Yageo | CFR-12JB-18K | Digikey | 18KEBK-ND | $0.02 | $0.00 | 0.125Wresistor | Cabinet
0 |  | RES | Carbon 1/6W, 5%, 20K | Yageo | CFR-12JB-20K | Digikey | 20KEBK-ND | $0.02 | $0.00 | 0.125Wresistor | Cabinet
0 |  | RES | Carbon 1/6W, 5%, 22K | Yageo | CFR-12JB-22K | Digikey | 22KEBK-ND | $0.02 | $0.00 | 0.125Wresistor | Cabinet
0 |  | RES | Carbon 1/6W, 5%, 27K | Yageo | CFR-12JB-27K | Digikey | 27KEBK-ND | $0.02 | $0.00 | 0.125Wresistor | Cabinet
0 |  | RES | Carbon 1/6W, 5%, 36K | Yageo | CFR-12JB-36K | Digikey | 36KEBK-ND | $0.02 | $0.00 | 0.125Wresistor | Cabinet
0 |  | RES | Carbon 1/6W, 5%, 33K | Yageo | CFR-12JB-33K | Digikey | 33KEBK-ND | $0.02 | $0.00 | 0.125Wresistor | Cabinet
0 |  | RES | Carbon 1/6W, 5%, 39K | Yageo | CFR-12JB-39K | Digikey | 39KEBK-ND | $0.02 | $0.00 | 0.125Wresistor | Cabinet
0 |  | RES | Carbon 1/6W, 5%, 47K | Yageo | CFR-12JB-47K | Digikey | 47KEBK-ND | $0.02 | $0.00 | 0.125Wresistor | Cabinet
0 |  | RES | Carbon 1/6W, 5%, 51K | Yageo | CFR-12JB-51K | Digikey | 51KEBK-ND | $0.02 | $0.00 | 0.125Wresistor | Cabinet
0 |  | RES | Carbon 1/6W, 5%, 56K | Yageo | CFR-12JB-56K | Digikey | 56KEBK-ND | $0.02 | $0.00 | 0.125Wresistor | Cabinet
0 |  | RES | Carbon 1/6W, 5%, 68K | Yageo | CFR-12JB-68K | Digikey | 68KEBK-ND | $0.02 | $0.00 | 0.125Wresistor | Cabinet
0 |  | RES | Carbon 1/6W, 5%, 82K | Yageo | CFR-12JB-82K | Digikey | 82KEBK-ND | $0.02 | $0.00 | 0.125Wresistor | Cabinet
0 |  | RES | Carbon 1/6W, 5%, 100K | Yageo | CFR-12JB-100K | Digikey | 100KEBK-ND | $0.02 | $0.00 | 0.125Wresistor | Cabinet
0 |  | RES | Carbon 1/6W, 5%, 120K | Yageo | CFR-12JB-120K | Digikey | 120KEBK-ND | $0.02 | $0.00 | 0.125Wresistor | Cabinet
0 |  | RES | Carbon 1/6W, 5%, 150K | Yageo | CFR-12JB-150K | Digikey | 150KEBK-ND | $0.02 | $0.00 | 0.125Wresistor | Cabinet
0 |  | RES | Carbon 1/6W, 5%, 180K | Yageo | CFR-12JB-180K | Digikey | 180KEBK-ND | $0.02 | $0.00 | 0.125Wresistor | Cabinet
0 |  | RES | Carbon 1/6W, 5%, 200K | Yageo | CFR-12JB-200K | Digikey | 200KEBK-ND | $0.02 | $0.00 | 0.125Wresistor | Cabinet
0 |  | RES | Carbon 1/6W, 5%, 220K | Yageo | CFR-12JB-220K | Digikey | 220KEBK-ND | $0.02 | $0.00 | 0.125Wresistor | Cabinet
0 |  | RES | Carbon 1/6W, 5%, 240K | Yageo | CFR-12JB-240K | Digikey | 240KEBK-ND | $0.02 | $0.00 | 0.125Wresistor | Cabinet
0 |  | RES | Carbon 1/6W, 5%, 270K | Yageo | CFR-12JB-270K | Digikey | 270KEBK-ND | $0.02 | $0.00 | 0.125Wresistor | Cabinet
0 |  | RES | Carbon 1/6W, 5%, 330K | Yageo | CFR-12JB-330K | Digikey | 330KEBK-ND | $0.02 | $0.00 | 0.125Wresistor | Cabinet
0 |  | RES | Carbon 1/6W, 5%, 390K | Yageo | CFR-12JB-390K | Digikey | 390KEBK-ND | $0.02 | $0.00 | 0.125Wresistor | Cabinet
0 |  | RES | Carbon 1/6W, 5%, 470K | Yageo | CFR-12JB-470K | Digikey | 470KEBK-ND | $0.02 | $0.00 | 0.125Wresistor | Cabinet
0 |  | RES | Carbon 1/6W, 5%, 510K | Yageo | CFR-12JB-510K | Digikey | 510KEBK-ND | $0.02 | $0.00 | 0.125Wresistor | Cabinet
0 |  | RES | Carbon 1/6W, 5%, 560K | Yageo | CFR-12JB-560K | Digikey | 560KEBK-ND | $0.02 | $0.00 | 0.125Wresistor | Cabinet
0 |  | RES | Carbon 1/6W, 5%, 680K | Yageo | CFR-12JB-680K | Digikey | 680KEBK-ND | $0.02 | $0.00 | 0.125Wresistor | Cabinet
0 |  | RES | Carbon 1/6W, 5%, 820K | Yageo | CFR-12JB-820K | Digikey | 820KEBK-ND | $0.02 | $0.00 | 0.125Wresistor | Cabinet
0 |  | RES | Carbon 1/6W, 5%, 1M | Yageo | CFR-12JB-1M0 | Digikey | 1.0MEBK-ND | $0.02 | $0.00 | 0.125Wresistor | Cabinet
0 |  | RES | Carbon 1/6W, 5%, 10M | Yageo | CFR-12JB-10M | Digikey | 10MEBK-ND | $0.02 | $0.00 | 0.125Wresistor | Cabinet
0 |  | SW | Tactile Switch, surface mount | C&K Components | KSC353JLFG | Mouser | 611-KSC353JLFG | $0.86 | $0.00 | KSC353JLFG | Cabinet
0 |  | SW | B3F tactile push button switch | Omron Electronics | B3F-1052 | Digikey | SW405-ND | $0.17 | $0.00 | B3F-1050 | Cabinet
0 |  | SW | Black Off board momentary push buttom |  |  | AllElectronics | MPB-5 | $0.35 | $0.00 | OffBoardSwitch | Professor
0 |  | SW | Red Off board momentary push buttom |  |  | AllElectronics | MPB-1 | $0.35 | $0.00 | OffBoardSwitch | Professor
0 |  | SW | On/off power switch |  |  |  |  | $0.85 | $0.00 | OffBoardPowerSwitch | Professor
0 |  | TRAN | PN2222 NPN transistor | Fairchild Semiconductor | PN2222 | Digikey | PN2222BU-ND | $0.13 | $0.00 | 2N2222 | Cabinet | be careful to get pins 1 and 3 correct, there are two versions of the chip: 2N2222 and PN2222
0 |  | TRAN | TIP120 Darlington NPN, TO220 | Fairchild | TIP120 | Digikey | TIP120-ND | $0.68 | $0.00 | TIP120 | Cabinet
0 |  | TRAN | TIP125 Darlington PNP, TO220 | Fairchild | TIP125 | Digikey | TIP125TU-ND | $0.67 | $0.00 | TIP125 | Cabinet
0 |  | TRAN | IRF540 MOSFET N-channel, TO220 |  | IRF540 | Digikey | IRF540NPBF-ND | $1.95 | $0.00 | IRF540 | Cabinet

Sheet: SurfaceMountParts
Quantity | REF DES | Type | Description | Manufacturer | Mfg. P/N | Distributor | P/N | Unit cost | Cost | PCB Artist | Where to get it?
0 |  | CAP | 0805 0.22 uF X7R ceramic |  |  |  |  | $0.14 | $0.00 | Ceramic0805 | Little box of surface mount parts
0 |  | CAP | 0805 220 pF C0G ceramic |  |  |  |  | $0.35 | $0.00 | Ceramic0805 | Little box of surface mount parts
0 |  | RES | 0805 1.1k 1% |  |  |  |  | $0.04 | $0.00 | 0.1WresistorSM805 | Little box of surface mount parts
0 |  | RES | 0805 10k 1% |  |  |  |  | $0.04 | $0.00 | 0.1WresistorSM805 | Little box of surface mount parts
0 |  | RES | 0805 20k 1% |  |  |  |  | $0.04 | $0.00 | 0.1WresistorSM805 | Little box of surface mount parts
0 |  | RES | 0805 25.5k 1% |  |  |  |  | $0.04 | $0.00 | 0.1WresistorSM805 | Little box of surface mount parts
0 |  | RES | 0805 100k 1% |  |  |  |  | $0.04 | $0.00 | 0.1WresistorSM805 | Little box of surface mount parts

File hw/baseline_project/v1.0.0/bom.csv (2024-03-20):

Designator | Footprint | Quantity | Value | LCSC Part #
C101, C102 | C_Axial_L5.1mm_D3.1mm_P15.00mm_Horizontal | 2 | 100nF
C103, C104 | CP_Axial_L10.0mm_D4.5mm_P15.00mm_Horizontal | 2 | 4.7uF
D101 | D_5W_P12.70mm_Horizontal | 1 | 1V0
J101 | Samtec_HPM-02-01-x-S_Straight_1x02_Pitch5.08mm | 1 | EXT_3V3
LS101 | PinHeader_1x02_P2.54mm_Vertical | 1 | Speaker
Q101 | vishay_IRLD024PBF | 1 | IRLD024PBF
R101 | R_Axial_DIN0411_L9.9mm_D3.6mm_P15.24mm_Horizontal | 1 | 10k
SW101 | SW_PUSH_6mm | 1 | UP
SW102 | SW_PUSH_6mm | 1 | DOWN
SW103 | SW_PUSH_6mm | 1 | LEFT
SW104 | SW_PUSH_6mm | 1 | RIGHT
SW105 | SW_PUSH_6mm | 1 | MODE
U101 | ti_EKTM4C123GXL | 1 | EK-TM4C123GXL
U102 | ai_thinker_ESP8266_01 | 1 | ESP8266-01/ESP-01
U103 | adafruit_st7735r | 1 | Adafruit ST7735R

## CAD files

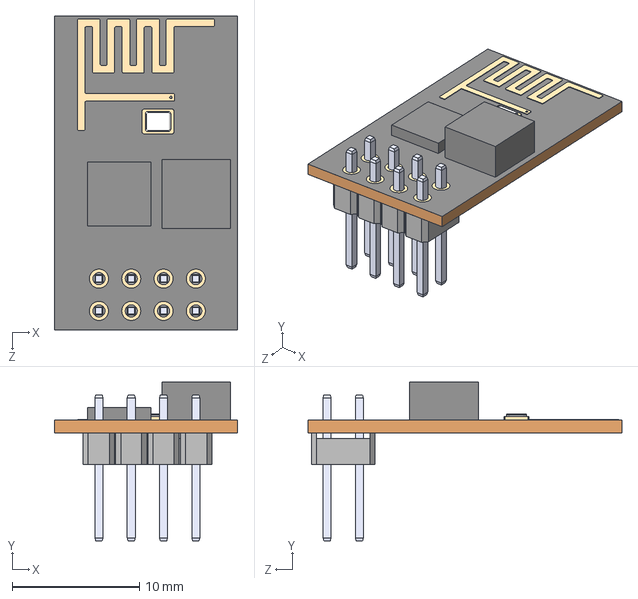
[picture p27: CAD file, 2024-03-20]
hw/baseline_project/models/ai_thinker_ESP8266-01.step
14.4 x 12.5 x 24.7 mm

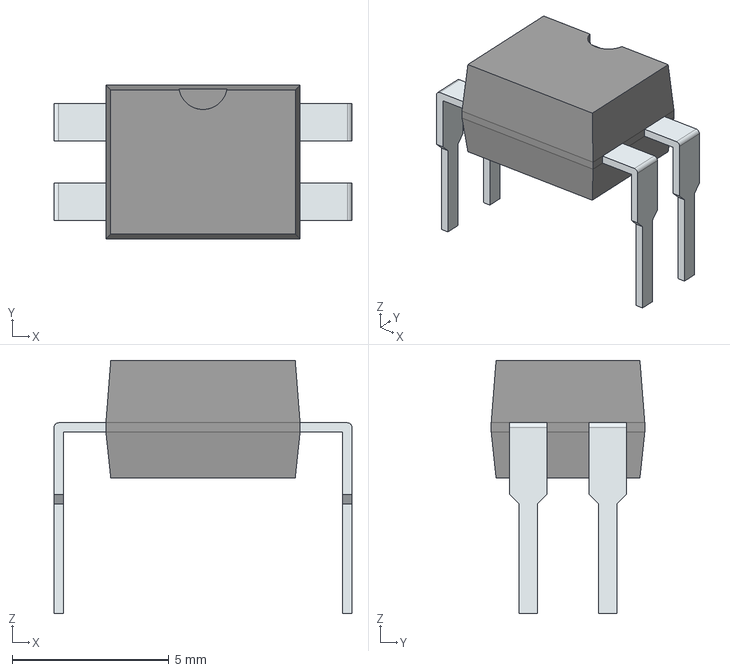
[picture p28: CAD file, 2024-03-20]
hw/baseline_project/models/vishay_IRLD024PBF.stp
9.51 x 4.90 x 8.07 mm
PinsArrayLR

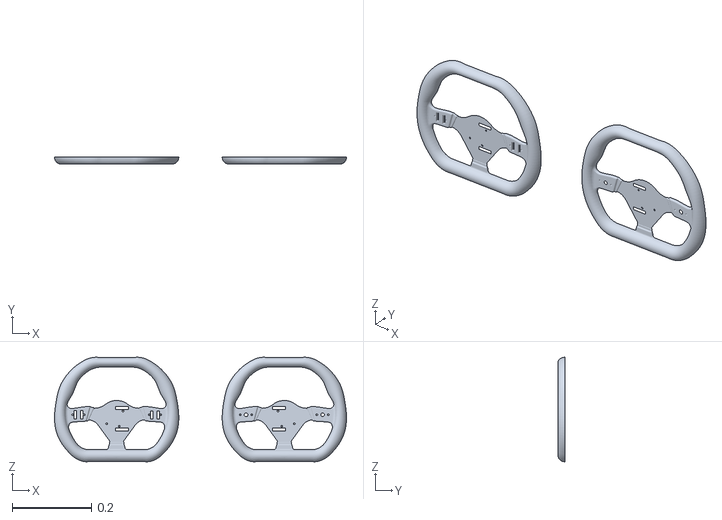
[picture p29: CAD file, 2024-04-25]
hw/wheel_models/garf_wheel_v4.stl
0.735 x 0.0175 x 0.263

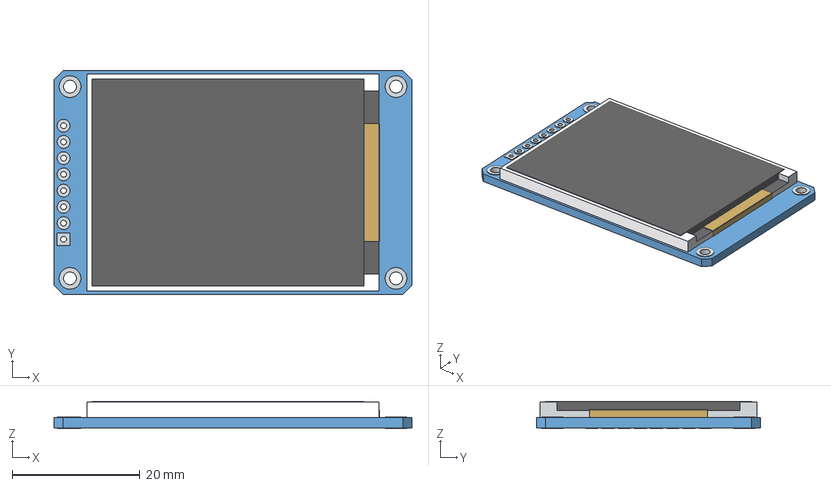
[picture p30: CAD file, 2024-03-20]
hw/baseline_project/models/adafruit_st7735r.stp
56.0 x 35.0 x 4.25 mm

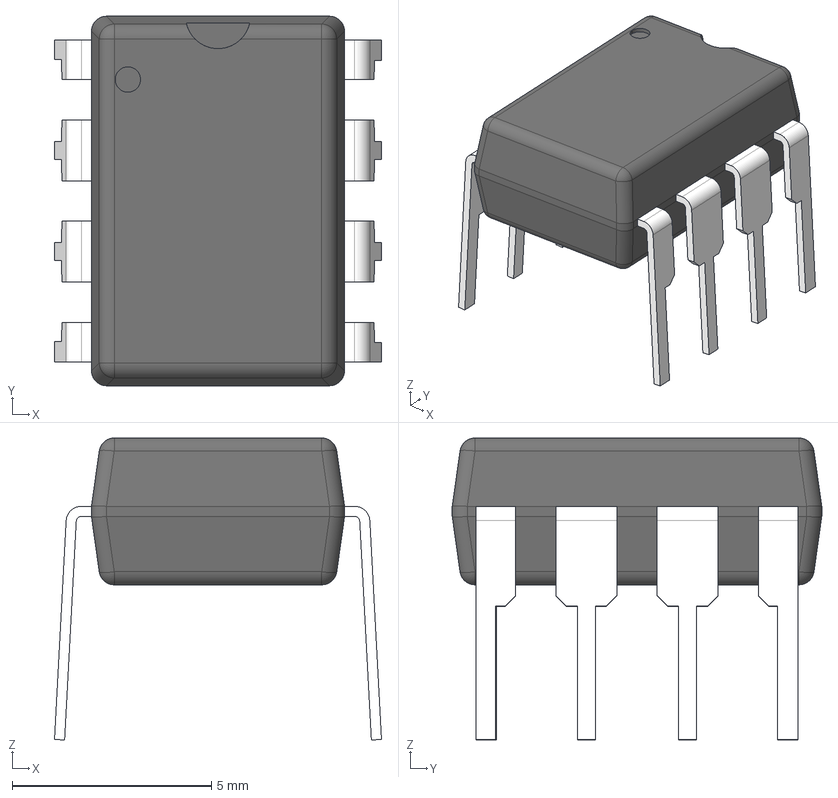
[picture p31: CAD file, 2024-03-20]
hw/baseline_project/models/ti_TLV5618AIP.stp
8.20 x 9.27 x 7.58 mm
BODY_P0008A
LEAD_P0008A x 4
LD_LHALF_P0008A x 2
LD_RHALF_P0008A x 2

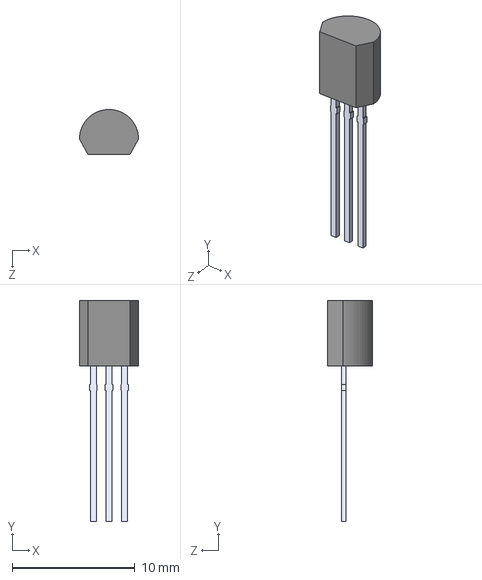
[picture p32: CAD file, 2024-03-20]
hw/baseline_project/models/ti_LM4041CILPR.step
4.82 x 18.0 x 3.68 mm

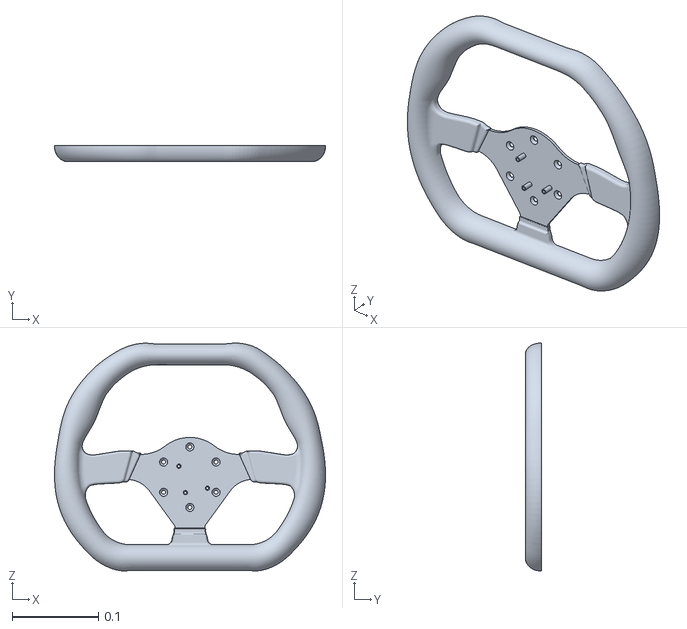
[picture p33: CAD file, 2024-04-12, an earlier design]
hw/wheel_models/garf_wheel_v1.stl
0.313 x 0.019 x 0.263

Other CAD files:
hw/wheel_models/garf_wheel_v3.stl
hw/wheel_models/garf_wheel_v2.stl

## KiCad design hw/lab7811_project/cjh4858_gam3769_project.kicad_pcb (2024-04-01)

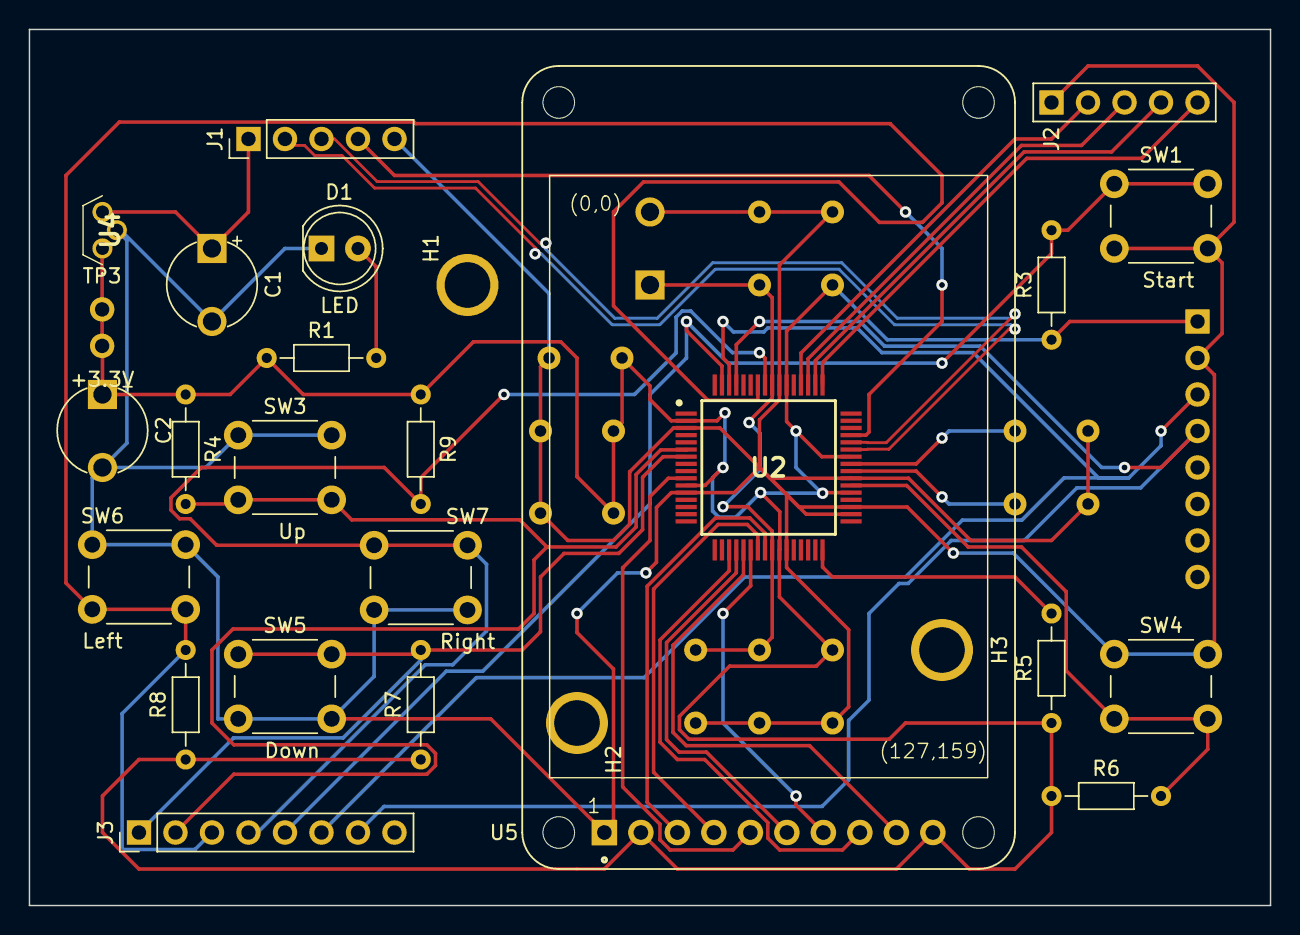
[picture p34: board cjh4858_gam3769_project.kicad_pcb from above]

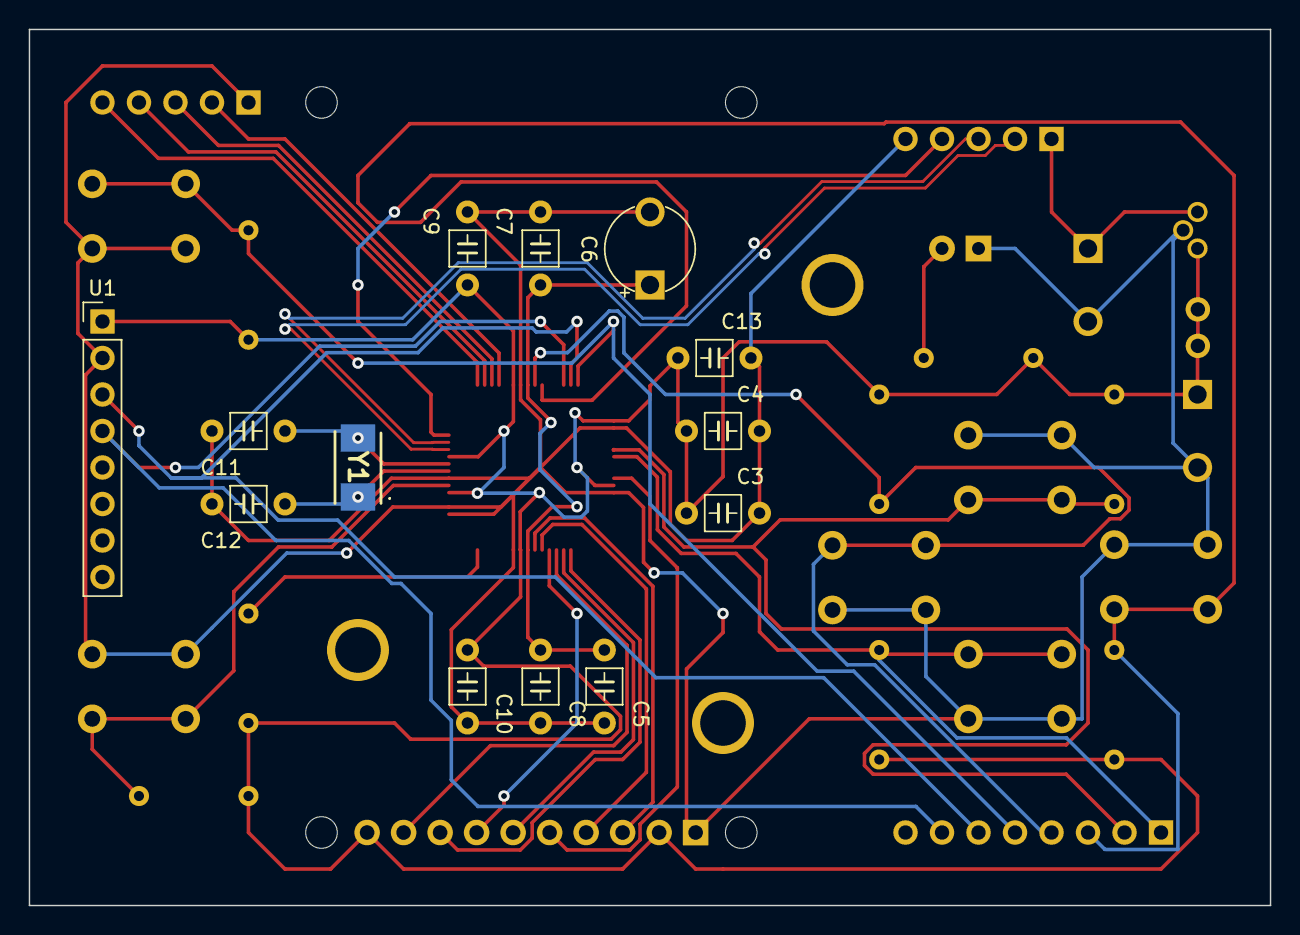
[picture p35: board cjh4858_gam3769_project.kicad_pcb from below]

Board: 2 copper layers, 86.4 x 61.0 mm, 40 parts (13 on the bottom side), 30 nets.

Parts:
C1, C2: 4.7uF; CP_Radial_Tantal200mil
C3, C10: 0.01uF; C_Axial_200mil
C4, C7, C8, C9: 0.1uF; C_Axial_200mil
C5, C13: 1uF; C_Axial_200mil
C6: 2.2uF; CP_Radial_Tantal200mil
C11, C12: 10pF C0G; C_Axial_200mil
D1: LED; LED_D5.0mm
H1, H2, H3: MountingHole_4_40
J1: Conn_01x05; PinHeader_1x05_P2.54mm_Vertical
J2: JTAG; PinHeader_1x05_P2.54mm_Vertical
J3: Conn_01x08_Pin; PinHeader_1x08_P2.54mm_Vertical
R1: 470; R_Axial_DIN0204_L3.6mm_D1.6mm_P7.62mm_Horizontal
R3, R4, R6, R7, R8, R9: 10k; R_Axial_DIN0204_L3.6mm_D1.6mm_P7.62mm_Horizontal
R5: 1M; R_Axial_DIN0204_L3.6mm_D1.6mm_P7.62mm_Horizontal
SW1: Start; SW_PUSH_6mm
SW3: Up; SW_PUSH_6mm
SW4: Reset; SW_PUSH_6mm
SW5: Down; SW_PUSH_6mm
SW6: Left; SW_PUSH_6mm
SW7: Right; SW_PUSH_6mm
TP3: +3.3V; Testpoint_1x02_P2.54mm
U1: MPU-6050; PinHeader_1x08_P2.54mm_Vertical
U2: TM4C123GH6PMIR; QFP50P1200X1200X160-64N
U4: LP2950-33LPRE3; TL431CLPM
U5: Adafruit ST7735R; adafruit_st7735r2
Y1: ABM3-16.000MHZ-B2-T; ABM3

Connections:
+3V3: C2.1, C3.1, C4.1, C9.1, C10.1, C13.1, R1.1, R3.1, R4.1, R5.1, R6.1, R7.1, R8.1, R9.1, TP3.1 (A), TP3.2 (B), U1.1 (CLKIN), U2.2 (VDDA), U2.11 (VDD_1), U2.26 (VDD_2), U2.37 (VBAT), U2.42 (VDD_3), U2.54 (VDD_4), U4.1 (OUTPUT), U5.2 (VCC), U5.10 (LITE)
/LDO: C5.1, C6.1, C7.1, C8.1, U2.25 (VDDC_1), U2.56 (VDDC_2)
/OSC1: C11.1, U2.41 (OSC1), Y1.2
/OSC2: C12.1, U2.40 (OSC0), Y1.1
/Reset: R6.2, SW4.2, U2.38 (~RST)
/TCK: J2.2 (B), U2.52 (PC0/TCK/SWCLK)
/TDI: J2.4 (C), U2.50 (PC2/TDI)
/TDO: J2.5 (C), U2.49 (PC3/TDO/SWO)
/TMS: J2.3 (C), U2.51 (PC1/TMS/SWDIO)
D+: J1.3, U2.44 (PD5)
D-: J1.2, U2.43 (PD4)
GND: C1.2, C2.2, C3.2, C4.2, C5.2, C6.2, C7.2, C8.2, C9.2, C10.2, C11.2, C12.2, C13.2, D1.1 (K), J1.5, J2.1 (A), SW1.2, SW3.1, SW4.1, SW5.2, SW6.1, SW7.2, U1.2 (NC), U2.3 (GNDA), U2.12 (GND_1), U2.27 (GND_2), U2.34 (XOSC0), U2.35 (GNDX), U2.39 (GND_3), U2.55 (GND_4), U4.2 (GND), U5.1 (GND)
unnamed: D1.2 (A), R1.2
unnamed: C1.1, J1.1, U4.3 (INPUT)
unnamed: R5.2, U2.32 (~WAKE)
PA2: U2.19 (PA2/SSI0C1K), U5.8 (SCK)
PA3: U2.20 (PA3/SSI0FSS), U5.6 (TFT_CS)
PA4: U2.21 (PA4/SSI0RX), U5.9 (MISO)
PA5: U2.22 (PA5/SSI0TX), U5.7 (MOSI)
PA6: U2.23 (PA6), U5.4 (D/C)
PA7: U2.24 (PA7), U5.3 (RESET)
PB0: J1.4, U2.45 (PB0/USB0ID)
PB4: J3.3, R8.2, SW6.2, U2.58 (PB4)
PB5: J3.4, R9.2, SW7.1, U2.57 (PB5)
PD0: J3.7, U1.4 (NC), U2.61 (PD0)
PD1: J3.6, U1.3 (NC), U2.62 (PD1)
PD2: J3.5, R3.2, SW1.1, U2.63 (PD2)
PD7: U2.10 (PD7), U5.5 (CARD_CS)
PE2: J3.1, R7.2, SW5.1, U2.7 (PE2)
PE3: J3.2, R4.2, SW3.2, U2.6 (PE3)

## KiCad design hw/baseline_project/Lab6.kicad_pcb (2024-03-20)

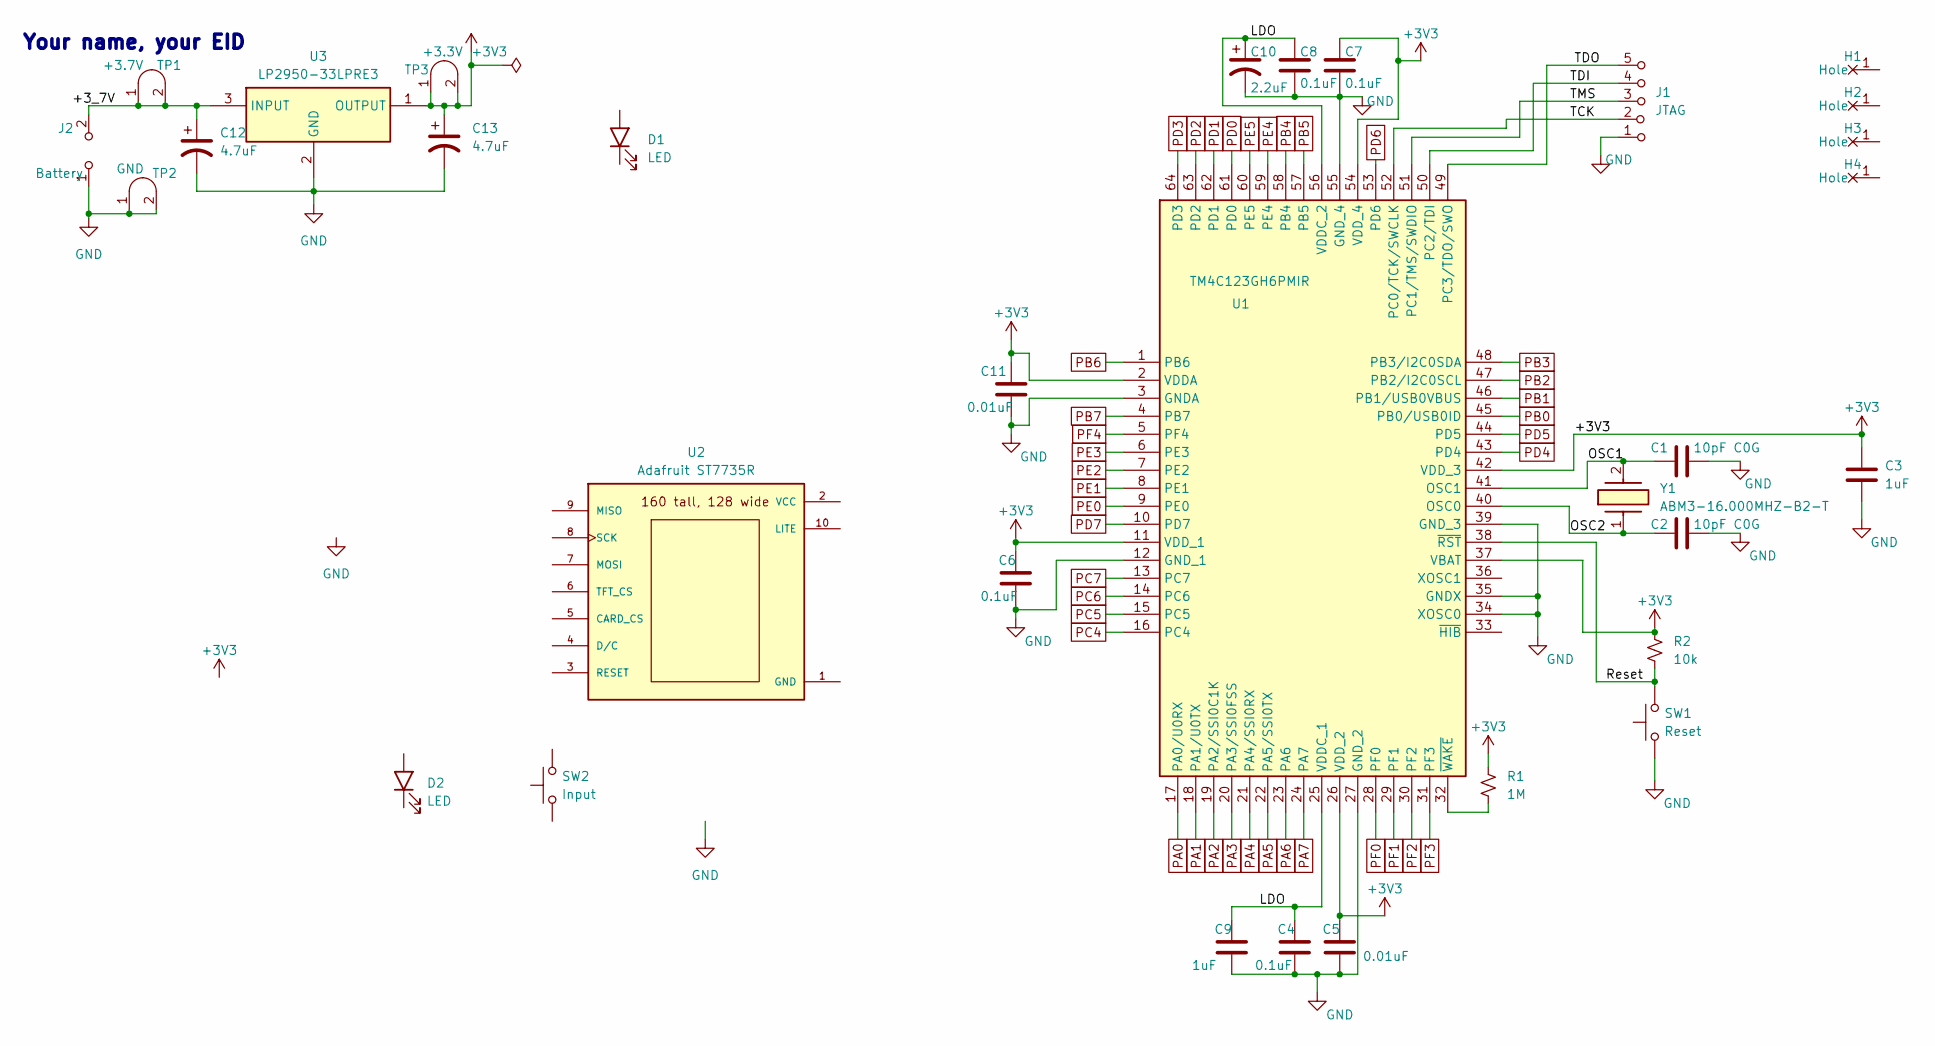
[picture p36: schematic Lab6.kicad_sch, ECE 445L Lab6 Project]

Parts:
C1, C2: 10pF C0G; C_Axial_200mil
C3, C9: 1uF; C_Axial_200mil
C4, C6, C7, C8: 0.1uF; C_Axial_200mil
C5, C11: 0.01uF; C_Axial_200mil
C10: 2.2uF; CP_Radial_Tantal200mil
C12, C13: 4.7uF; CP_Radial_Tantal200mil
D1, D2: LED; LED_D5.0mm
H1, H2, H3, H4: MountingHole_4_40
J1: JTAG; PinHeader_1x05_P2.54mm_Vertical
J2: Battery; PinHeader_1x02_P2.54mm_Vertical
R1: 1M; R_Axial_DIN0204_L3.6mm_D1.6mm_P7.62mm_Horizontal
R2: 10k; R_Axial_DIN0204_L3.6mm_D1.6mm_P7.62mm_Horizontal
SW1: Reset; SW_PUSH_6mm
SW2: Input; SW_PUSH_6mm
TP1: +3.7V; Testpoint_1x02_P2.54mm
TP2: GND; Testpoint_1x02_P2.54mm
TP3: +3.3V; Testpoint_1x02_P2.54mm
U1: TM4C123GH6PMIR; QFP50P1200X1200X160-64N; Mouser Part Number 595-TM4C123GH6PMIR
U2: Adafruit ST7735R; adafruit_st7735r2
U3: LP2950-33LPRE3; TL431CLPM; Mouser Part Number 595-LP2950-33LPRE3
Y1: ABM3-16.000MHZ-B2-T; ABM3; Mouser Part Number 815-ABM3-16-B2-T

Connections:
+3V3: C3.1, C5.1, C6.1, C7.1, C11.1, C13.1, R1.1, R2.1, TP3.1 (A), TP3.2 (B), U1.2 (VDDA), U1.11 (VDD_1), U1.26 (VDD_2), U1.37 (VBAT), U1.42 (VDD_3), U1.54 (VDD_4), U3.1 (OUTPUT)
/+3_7V: C12.1, J2.2 (B), TP1.1 (A), TP1.2 (B), U3.3 (INPUT)
/LDO: C4.1, C8.1, C9.1, C10.1, U1.25 (VDDC_1), U1.56 (VDDC_2)
/OSC1: C1.1, U1.41 (OSC1), Y1.2
/OSC2: C2.1, U1.40 (OSC0), Y1.1
/Reset: R2.2, SW1.2, U1.38 (~RST)
/TCK: J1.2 (B), U1.52 (PC0/TCK/SWCLK)
/TDI: J1.4 (C), U1.50 (PC2/TDI)
/TDO: J1.5 (C), U1.49 (PC3/TDO/SWO)
/TMS: J1.3 (C), U1.51 (PC1/TMS/SWDIO)
GND: C1.2, C2.2, C3.2, C4.2, C5.2, C6.2, C7.2, C8.2, C9.2, C10.2, C11.2, C12.2, C13.2, J1.1 (A), J2.1 (A), SW1.1, TP2.1 (A), TP2.2 (B), U1.3 (GNDA), U1.12 (GND_1), U1.27 (GND_2), U1.34 (XOSC0), U1.35 (GNDX), U1.39 (GND_3), U1.55 (GND_4), U3.2 (GND)
unnamed: R1.2, U1.32 (~WAKE)
PA0: U1.17 (PA0/U0RX)
PA1: U1.18 (PA1/U0TX)
PA2: U1.19 (PA2/SSI0C1K)
PA3: U1.20 (PA3/SSI0FSS)
PA4: U1.21 (PA4/SSI0RX)
PA5: U1.22 (PA5/SSI0TX)
PA6: U1.23 (PA6)
PA7: U1.24 (PA7)
PB0: U1.45 (PB0/USB0ID)
PB1: U1.46 (PB1/USB0VBUS)
PB2: U1.47 (PB2/I2C0SCL)
PB3: U1.48 (PB3/I2C0SDA)
PB4: U1.58 (PB4)
PB5: U1.57 (PB5)
PB6: U1.1 (PB6)
PB7: U1.4 (PB7)
PC4: U1.16 (PC4)
PC5: U1.15 (PC5)
PC6: U1.14 (PC6)
PC7: U1.13 (PC7)
PD0: U1.61 (PD0)
PD1: U1.62 (PD1)
PD2: U1.63 (PD2)
PD3: U1.64 (PD3)
PD4: U1.43 (PD4)
PD5: U1.44 (PD5)
PD6: U1.53 (PD6)
PD7: U1.10 (PD7)
PE0: U1.9 (PE0)
PE1: U1.8 (PE1)
PE2: U1.7 (PE2)
PE3: U1.6 (PE3)
PE4: U1.59 (PE4)
PE5: U1.60 (PE5)
PF0: U1.28 (PF0)
PF1: U1.29 (PF1)
PF2: U1.30 (PF2)
PF3: U1.31 (PF3)
PF4: U1.5 (PF4)

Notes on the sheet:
Your name, your EID

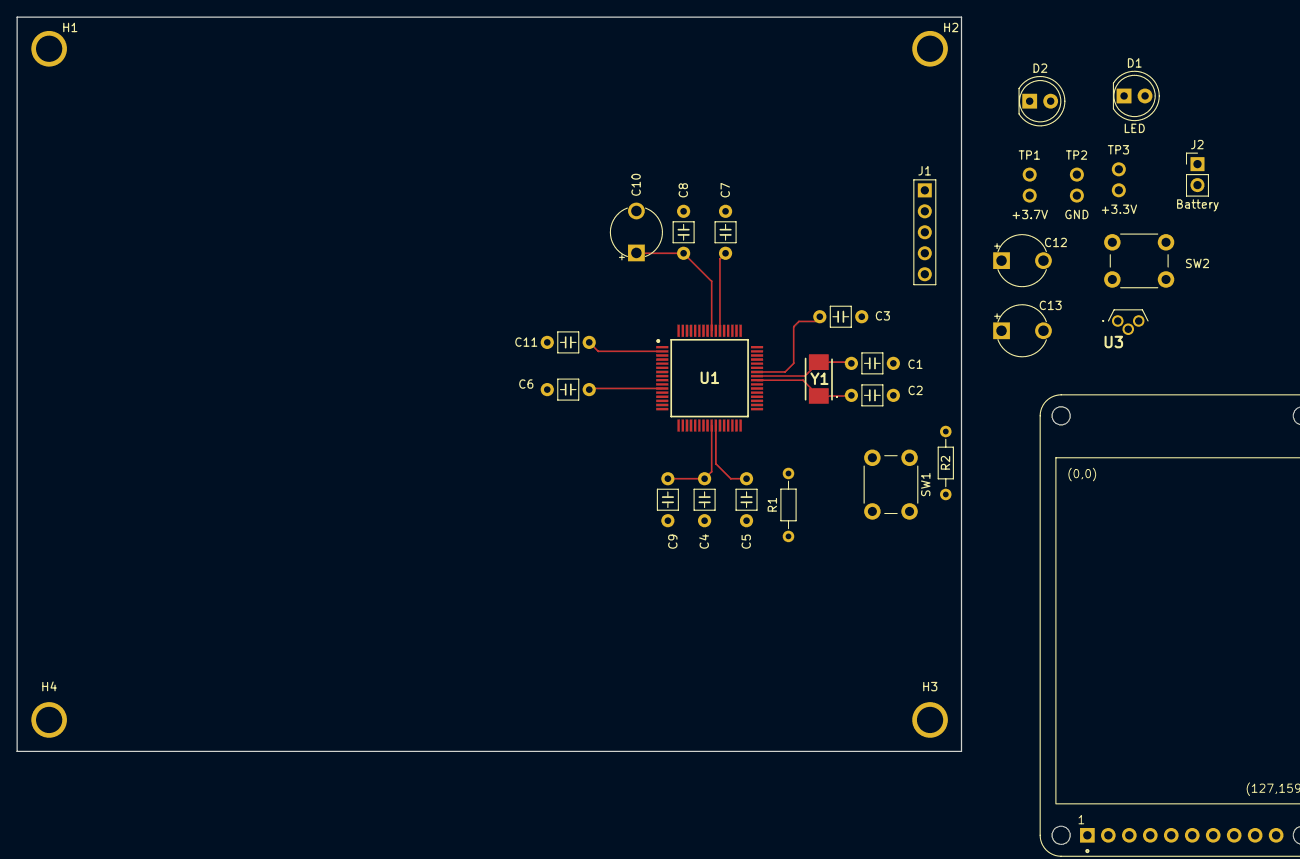
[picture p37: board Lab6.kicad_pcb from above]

Board: 2 copper layers, 114.4 x 88.9 mm, 32 parts (0 on the bottom side), 12 nets.

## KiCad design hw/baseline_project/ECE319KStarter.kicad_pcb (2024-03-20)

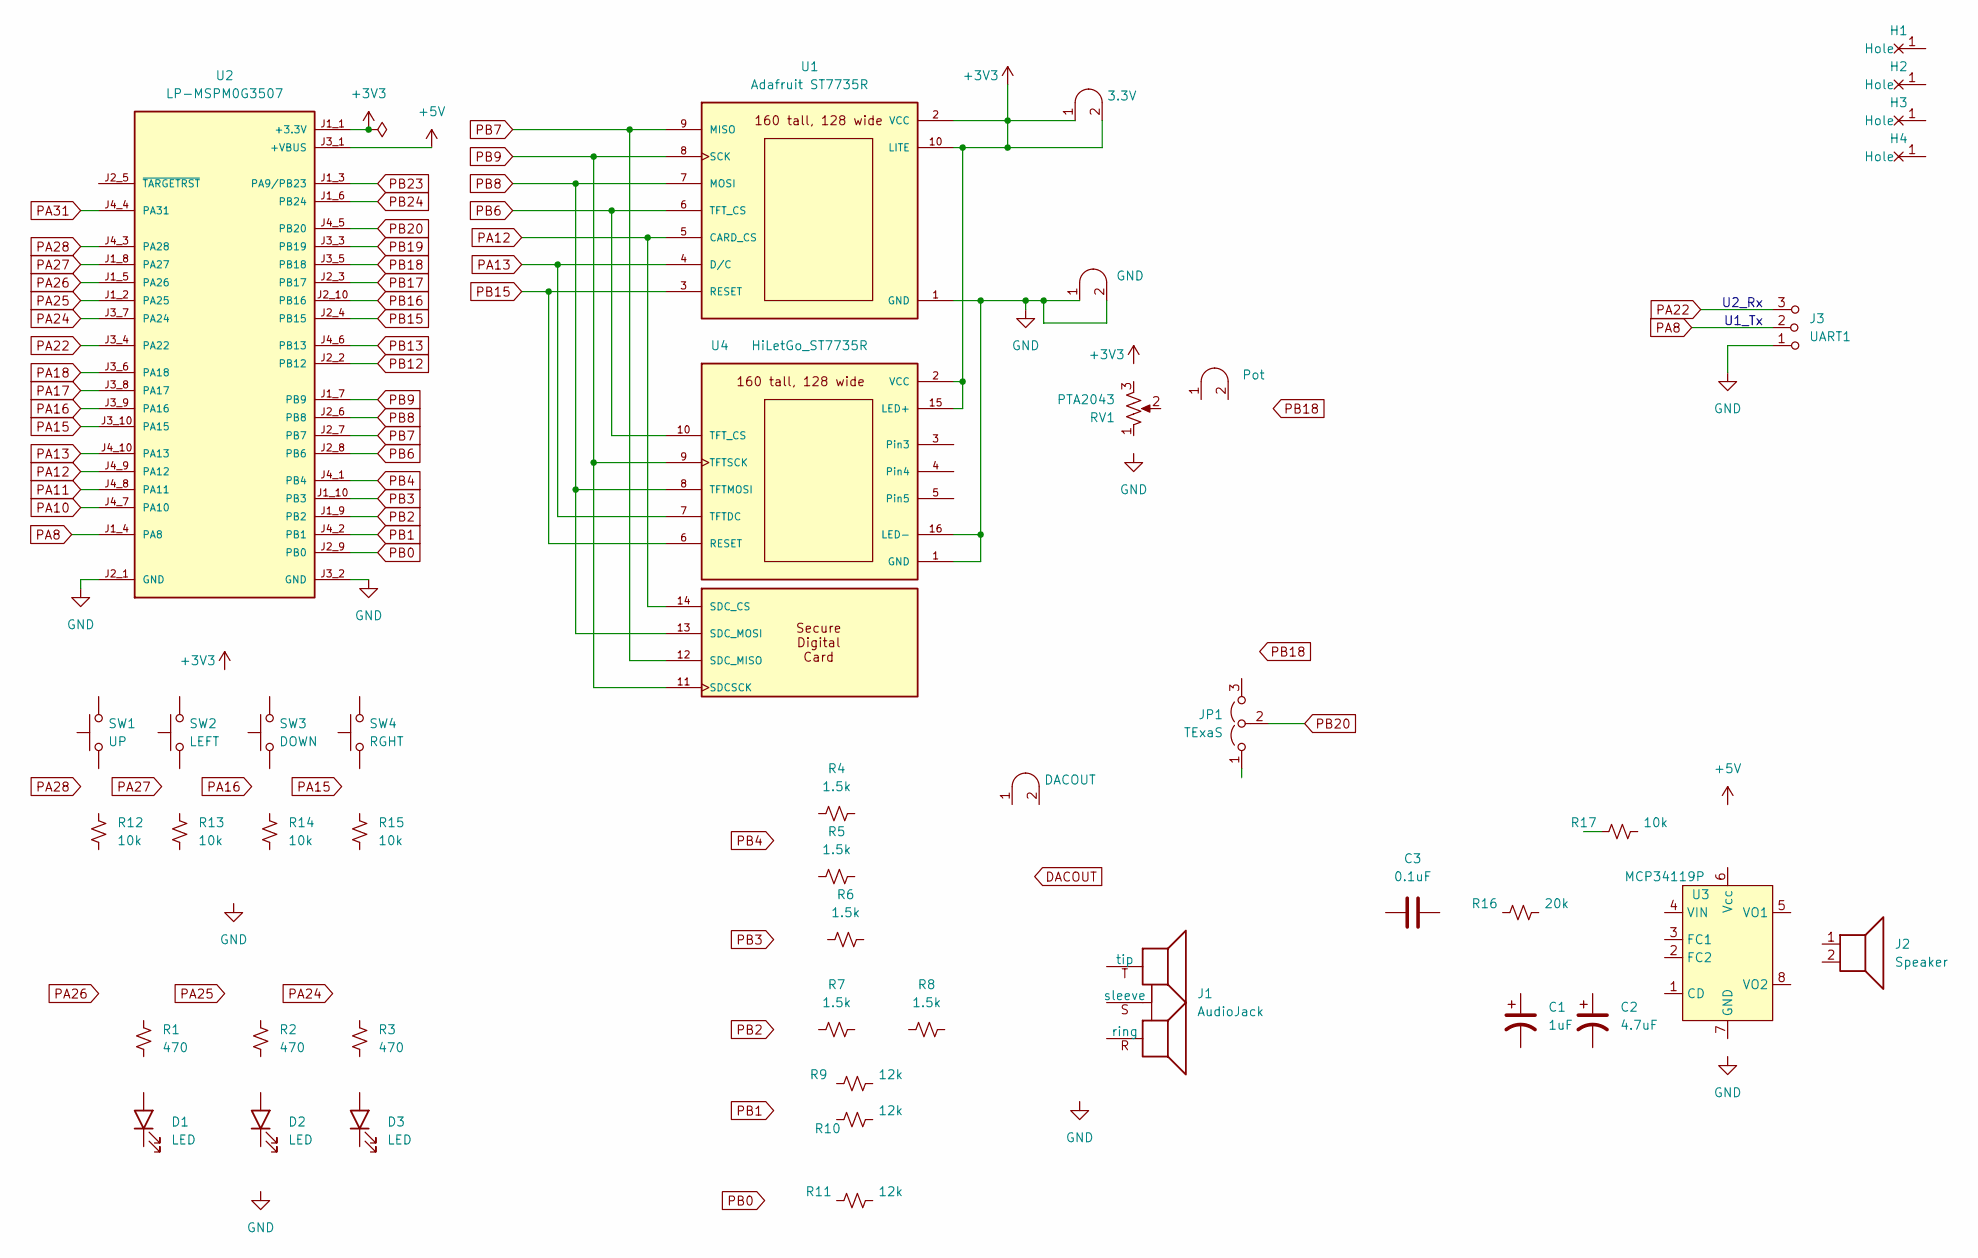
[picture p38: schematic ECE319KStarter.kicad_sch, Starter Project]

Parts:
C1: 1uF; CP_Radial_Tantal200mil
C2: 4.7uF; CP_Radial_Tantal200mil
C3: 0.1uF; C_Axial_200mil
D1, D2, D3: LED; LED_D5.0mm
H1, H2, H3, H4: MountingHole_4_40
J1: AudioJack; Jack_3.5mm_CUI_SJ1-3523N_Horizontal
J2: Speaker; PinHeader_1x02_P2.54mm_Vertical
J3: UART1; PinHeader_1x03_P2.54mm_Vertical
J4: Pot; Testpoint_1x02_P2.54mm
J6: GND; Testpoint_1x02_P2.54mm
J7: DACOUT; Testpoint_1x02_P2.54mm
JP1: TExaS; PinHeader_1x03_P2.54mm_Vertical
R1, R2, R3: 470; R_Axial_DIN0204_L3.6mm_D1.6mm_P7.62mm_Horizontal
R4, R5, R6, R7, R8: 1.5k; R_Axial_DIN0204_L3.6mm_D1.6mm_P7.62mm_Horizontal
R9, R10, R11: 12k; R_Axial_DIN0204_L3.6mm_D1.6mm_P7.62mm_Horizontal
R12, R13, R14, R15, R17: 10k; R_Axial_DIN0204_L3.6mm_D1.6mm_P7.62mm_Horizontal
R16: 20k; R_Axial_DIN0204_L3.6mm_D1.6mm_P7.62mm_Horizontal
RV1: PTA2043; PTA2043pot
SW1: UP; SW_PUSH_6mm
SW2: LEFT; SW_PUSH_6mm
SW3: DOWN; SW_PUSH_6mm
SW4: RGHT; SW_PUSH_6mm
TP1: 3.3V; Testpoint_1x02_P2.54mm
U1: Adafruit ST7735R; adafruit_st7735r2
U2: LP-MSPM0G3507; ti_LP_MSPM0G3507
U3: MCP34119P; DIP-8_W7.62mm_LongPads
U4: HiLetGo_ST7735R; hiletgo_st7735r

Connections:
+3V3: TP1.1 (A), TP1.2 (B), U1.2 (VCC), U1.10 (LITE), U2.J1_1 (+3.3V), U4.2 (VCC), U4.15 (LED+)
+5V: U2.J3_1 (+VBUS)
GND: J3.1 (A), J6.1 (A), J6.2 (B), U1.1 (GND), U2.J2_1 (GND), U2.J3_2 (GND), U4.1 (GND), U4.16 (LED-)
PA8: J3.2 (B), U2.J1_4 (PA8)
PA10: U2.J4_7 (PA10)
PA11: U2.J4_8 (PA11)
PA12: U1.5 (CARD_CS), U2.J4_9 (PA12), U4.14 (SDC_CS)
PA13: U1.4 (D/C), U2.J4_10 (PA13), U4.7 (TFTDC)
PA15: U2.J3_10 (PA15)
PA16: U2.J3_9 (PA16)
PA17: U2.J3_8 (PA17)
PA18: U2.J3_6 (PA18)
PA22: J3.3 (C), U2.J3_4 (PA22)
PA24: U2.J3_7 (PA24)
PA25: U2.J1_2 (PA25)
PA26: U2.J1_5 (PA26)
PA27: U2.J1_8 (PA27)
PA28: U2.J4_3 (PA28)
PA31: U2.J4_4 (PA31)
PB0: U2.J2_9 (PB0)
PB1: U2.J4_2 (PB1)
PB2: U2.J1_9 (PB2)
PB3: U2.J1_10 (PB3)
PB4: U2.J4_1 (PB4)
PB6: U1.6 (TFT_CS), U2.J2_8 (PB6), U4.10 (TFT_CS)
PB7: U1.9 (MISO), U2.J2_7 (PB7), U4.12 (SDC_MISO)
PB8: U1.7 (MOSI), U2.J2_6 (PB8), U4.8 (TFTMOSI), U4.13 (SDC_MOSI)
PB9: U1.8 (SCK), U2.J1_7 (PB9), U4.9 (TFTSCK), U4.11 (SDCSCK)
PB12: U2.J2_2 (PB12)
PB13: U2.J4_6 (PB13)
PB15: U1.3 (RESET), U2.J2_4 (PB15), U4.6 (RESET)
PB16: U2.J2_10 (PB16)
PB17: U2.J2_3 (PB17)
PB18: U2.J3_5 (PB18)
PB19: U2.J3_3 (PB19)
PB20: JP1.2 (C), U2.J4_5 (PB20)
PB23: U2.J1_3 (PA9/PB23)
PB24: U2.J1_6 (PB24)

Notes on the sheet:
U2_Rx
U1_Tx

Board: 2 copper layers, 44 parts (1 on the bottom side), 12 nets, no tracks yet.

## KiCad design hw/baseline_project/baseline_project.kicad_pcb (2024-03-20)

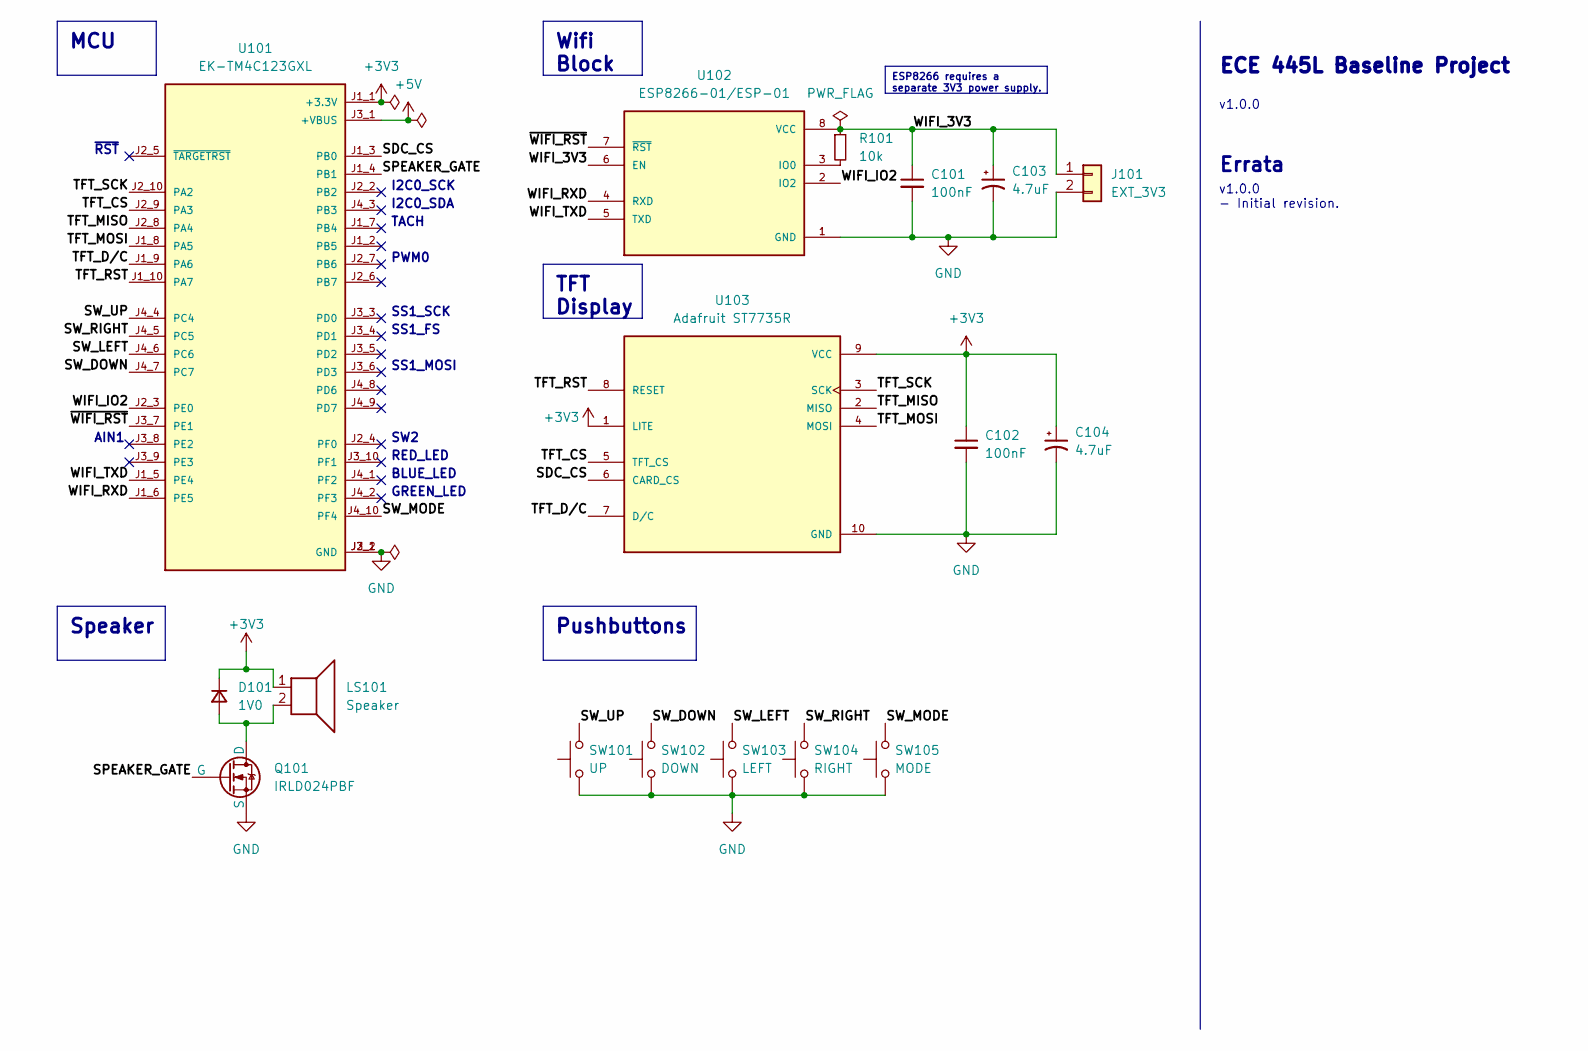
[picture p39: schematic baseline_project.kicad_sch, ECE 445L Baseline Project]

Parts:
C101, C102: 100nF; C_Axial_L5.1mm_D3.1mm_P15.00mm_Horizontal
C103, C104: 4.7uF; CP_Axial_L10.0mm_D4.5mm_P15.00mm_Horizontal
D101: 1V0; D_5W_P12.70mm_Horizontal
J101: EXT_3V3; Samtec_HPM-02-01-x-S_Straight_1x02_Pitch5.08mm
LS101: Speaker; PinHeader_1x02_P2.54mm_Vertical
Q101: IRLD024PBF; vishay_IRLD024PBF
R101: 10k; R_Axial_DIN0411_L9.9mm_D3.6mm_P15.24mm_Horizontal
SW101: UP; SW_PUSH_6mm
SW102: DOWN; SW_PUSH_6mm
SW103: LEFT; SW_PUSH_6mm
SW104: RIGHT; SW_PUSH_6mm
SW105: MODE; SW_PUSH_6mm
U101: EK-TM4C123GXL; ti_EKTM4C123GXL
U102: ESP8266-01/ESP-01; ai_thinker_ESP8266_01
U103: Adafruit ST7735R; adafruit_st7735r

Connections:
+3V3: C102.1, C104.1, D101.1 (K), LS101.1, U101.J1_1 (+3.3V), U103.1 (LITE), U103.9 (VCC)
+5V: U101.J3_1 (+VBUS)
/SDC_CS: U101.J1_3 (PB0), U103.6 (CARD_CS)
/SPEAKER_GATE: Q101.2 (G), U101.J1_4 (PB1)
/SW_DOWN: SW102.2, U101.J4_7 (PC7)
/SW_LEFT: SW103.2, U101.J4_6 (PC6)
/SW_MODE: SW105.2, U101.J4_10 (PF4)
/SW_RIGHT: SW104.2, U101.J4_5 (PC5)
/SW_UP: SW101.2, U101.J4_4 (PC4)
/TFT_CS: U101.J2_9 (PA3), U103.5 (TFT_CS)
/TFT_D/C: U101.J1_9 (PA6), U103.7 (D/C)
/TFT_MISO: U101.J2_8 (PA4), U103.2 (MISO)
/TFT_MOSI: U101.J1_8 (PA5), U103.4 (MOSI)
/TFT_RST: U101.J1_10 (PA7), U103.8 (RESET)
/TFT_SCK: U101.J2_10 (PA2), U103.3 (SCK)
/WIFI_3V3: C101.1, C103.1, J101.1, R101.1, U102.6 (EN), U102.8 (VCC)
/WIFI_IO2: U101.J2_3 (PE0), U102.2 (IO2)
/WIFI_RXD: U101.J1_6 (PE5), U102.4 (RXD)
/WIFI_TXD: U101.J1_5 (PE4), U102.5 (TXD)
/~WIFI_RST: U101.J3_7 (PE1), U102.7 (~RST)
GND: C101.2, C102.2, C103.2, C104.2, J101.2, Q101.3 (S), SW101.1, SW102.1, SW103.1, SW104.1, SW105.1, U101.J2_1 (GND), U101.J3_2 (GND), U102.1 (GND), U103.10 (GND)
unnamed: D101.2 (A), LS101.2, Q101.1 (D)
unnamed: R101.2, U102.3 (IO0)

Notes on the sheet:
MCU
ESP8266 requires a separate 3V3 power supply.
Speaker
Pushbuttons
TFT Display
Wifi Block
SS1_FS
SS1_MOSI
I2C0_SCK
v1.0.0 - Initial revision.
~{RST}
PWM0
TACH
AIN1
ECE 445L Baseline Project
v1.0.0
Errata
BLUE_LED
I2C0_SDA
SS1_SCK
RED_LED
SW2
GREEN_LED

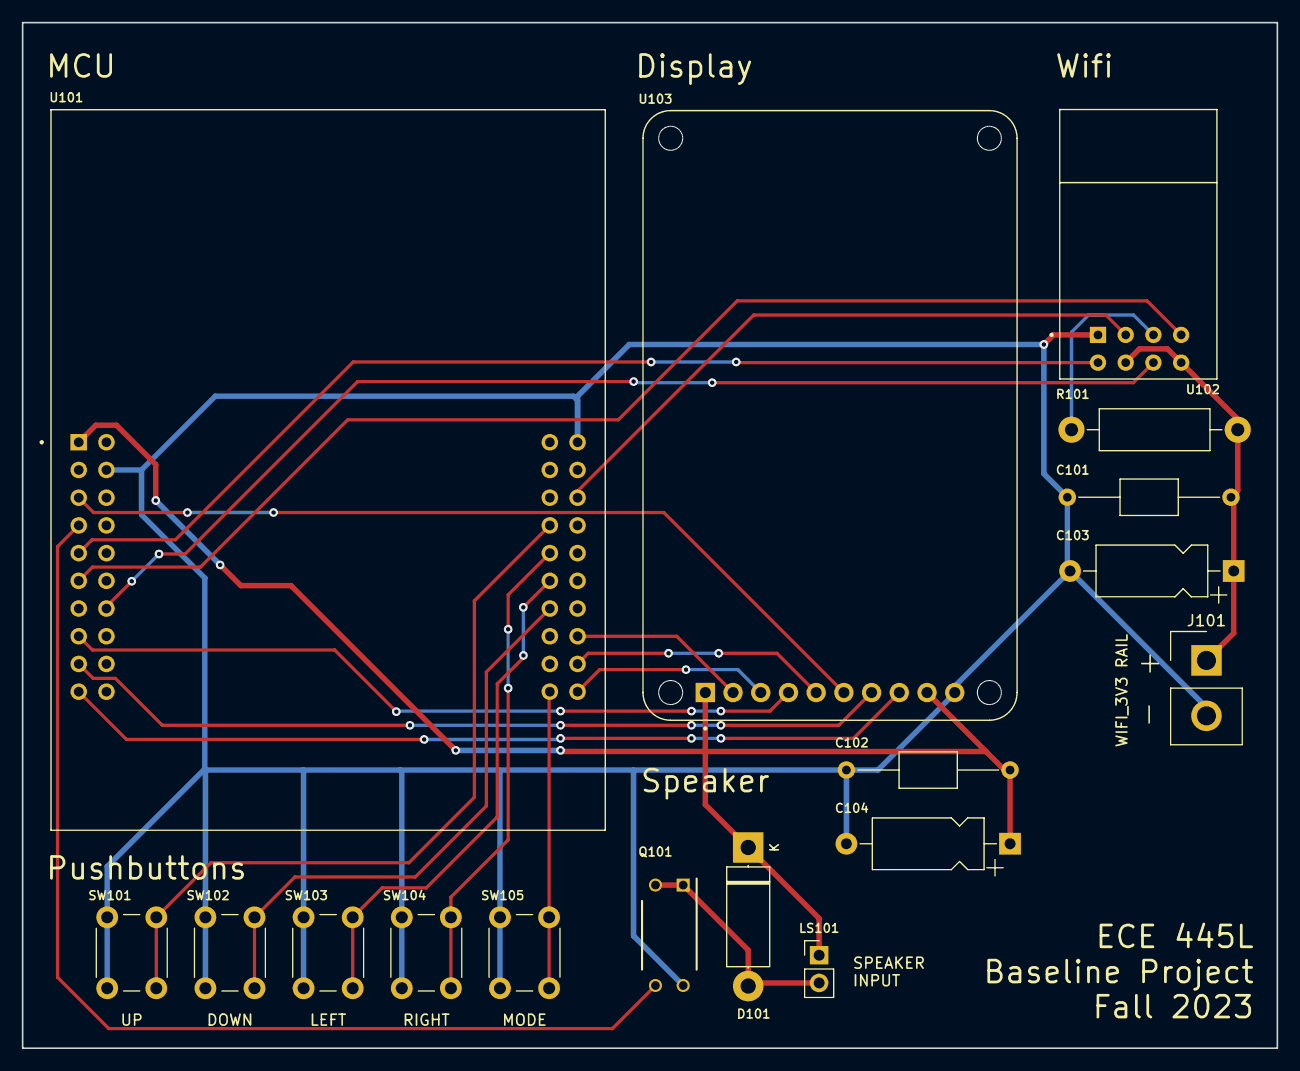
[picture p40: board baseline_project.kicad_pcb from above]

Board: 2 copper layers, 115.0 x 94.0 mm, 17 parts (0 on the bottom side), 22 nets.

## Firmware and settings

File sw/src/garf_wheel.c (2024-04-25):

///**
// * @file garf_wheel.c
// * @authors: Gabriel Moore and Calvin Heischman
// * @brief
// *    This code turns the TM4C into a generic USB HID gamepad device that
// *    interfaces with the host like a steering wheel. It's gyro enabled
// *    and can play Garfield Kart. Cool shit overall <3
// * 
// *    Have fun garf karting!
// * 
// * @version 69.420
// * @date 04-12-2024
// *
// * @copyright Copyright (c) 2024
// * @note Potential Pinouts: (FILL OUT LATER)
// *    USB:
// *    Buttons (recommended garfield kart keybind):
// *				MODE 1 [1 pulse LED]: Full controls w/ gyro
// *				MODE 2 [2 pulse LED]:	No gryo, just use left/right buttons to steer with accelerate auto on
// *			Start: PD2	(bind to forwards)
// *			Reset: RST
// *			Up:		 PE3	(TOGGLE MODE  --  only impacts the following 3 buttons)
// *			Right: PB5	1:(bind to pause) 		2:(bind to right steering)
// *			Down:	 PE2	1:(bind to backwards) 2:(bind to toggle off/forwards)
// *			Left:	 PB4	1:(bind to drift) 		2:(bind to left steering)
// *    Gyro: (directions subject to change based on mounting)
// *			X:	Left-right steering
// *			Y:	Forward-back throw item
// *			Z:	*unused*	--	would overcomplicate controls
// *		ST7735:

// *    Garfield Binds:
// *			Left:		turn left
// *			Right:	turn right
// *			Start:	drive (TOGGLE)
// *			Up:			ability forward
// *			Right:	play/pause
// *			Down:		ability backward
// *			Left:		brake
// *			Back:		drift

// Copyright 2024 by Gabriel Moore & Calvin Heischman (copy our code if you dare, it's not even that good you dork)
#include "garf_handler.h"
#include "menu.h"
#include "switches.h"

enum garfstate g_iGamepadState;

// An activity counter to slow the LED blink down to a visible rate.
static uint32_t g_ui32Updates;
// The error routine that is called if the driver library encounters an error.
#ifdef DEBUG
void
__error__(char *pcFilename, uint32_t ui32Line)
{
}
#endif
// Macro used to convert the 12-bit unsigned values to an eight bit signed value returned in the HID report.
// This maps the values from the ADC that range from 0 to 2047 over to 127 to -128.
#define Convert8Bit(ui32Value)  ((int8_t)((0x7ff - ui32Value) >> 4))

#include <stdint.h>
#include <stdbool.h>
#include <stdlib.h>
#include "inc/hw_memmap.h"
#include "inc/hw_types.h"
#include "driverlib/debug.h"
#include "driverlib/gpio.h"
#include "driverlib/sysctl.h"
#include "driverlib/usb.h"
#include "usblib/usblib.h"
#include "usblib/usbhid.h"

#define PB4		(*((volatile uint32_t *)0x40005040))  
	
//	***	CHANGE BASED ON WHAT YOU'RE RUNNING ON	***	//
#define PCB false

struct buttholes_t prev_press;


int main(void){
		displayinit();	
		gyro_state = 1;
		uint32_t hold = 1;
    uint8_t ui8ButtonsChanged, ui8Buttons;
    bool bUpdate;
		//printf("PASS 1\n");
		prev_press.start = 1;prev_press.up = 1;prev_press.right = 1;prev_press.down = 1;prev_press.left = 1;
		//printf("PASS 2\n");
    usb_inits(PCB);	//inits PLL, GPIO, ADC/GYRO, UART, Buttons, and HID dependencies
		//printf("PASS 3\n");	
	

/* 	Main usb device handling:
			1) WAIT FOR HOST CONNECTION
			2) IF DISCONNECT: RETURN TO TOP AND WAIT FOR NEW CONNECTION	*/
    while(1){
				uint32_t ui32PortD = ROM_GPIOPinRead(GPIO_PORTD_AHB_BASE, GPIO_PIN_2);
				//uint32_t ui32PortD = 1;
        // Wait here until USB device is connected to a host.
				//printf("PASS MAIN\n");	
				if(PCB) g_iGamepadState = eStateIdle;
        if(g_iGamepadState == eStateIdle)
        {					
            // No update by default.
            bUpdate = false;
					
						headbounce();
						sReport.ui8Buttons = 0;
						//implementing non-board buttons
						//start: 0x4, urdl: 0x8,0x10,0x20,0x40
						struct buttholes_t assfingered = getbuttons(ui32PortD);
						//if buttons are different from previous state
						if((assfingered.start != prev_press.start)||(assfingered.up != prev_press.up)||(assfingered.right != prev_press.right)||(assfingered.down != prev_press.down)||(assfingered.left != prev_press.left)||(assfingered.left_L != prev_press.left_L)||(assfingered.right_R != prev_press.right_R)){
							//if ass is 1, release task
							if(assfingered.start == 0) sReport.ui8Buttons |= 0x4;
							if(assfingered.up == 0) sReport.ui8Buttons |= 0x8;
							if(assfingered.right == 0) sReport.ui8Buttons |= 0x10;
							if(assfingered.down == 0) sReport.ui8Buttons |= 0x20;
							if(assfingered.left == 0) sReport.ui8Buttons |= 0x40;
						if(assfingered.right_R == 0) sReport.ui8Buttons |= 0x1;
						if(assfingered.left_L == 0) sReport.ui8Buttons |= 0x2;
							uint32_t new_buttons = ((assfingered.start << 4)+(assfingered.up << 3)+(assfingered.right << 2)+(assfingered.down << 1)+(assfingered.left));
							prev_press.start = assfingered.start;
							prev_press.up = assfingered.up;
							prev_press.right = assfingered.right;
							prev_press.down = assfingered.down;
							prev_press.left = assfingered.left;
							prev_press.right_R = assfingered.right_R;
							prev_press.left_L = assfingered.left_L;
							//printf("%d %d %d %d %d\n",assfingered.start,assfingered.up,assfingered.left,assfingered.down,assfingered.right);
							if(assfingered.start==0) hold^=1;
							if((assfingered.start==0)||(assfingered.up==0)||(assfingered.right==0)||(assfingered.left==0)||(assfingered.down==0)) menuhandler(new_buttons);
							bUpdate = true;
						}
						//printf("PASS 4\n");	
						
						//update based on gyrostate
						if(((gyro_state&0x2)>>1) == 1){
							//drunk driving
							sReport.ui8Buttons = rand();
							sReport.i8XPos = rand();
							sReport.i8YPos = rand();
							sReport.i8ZPos = rand();
						}
						if(((gyro_state&0x4)>>2) == 1){
							//garfield kart
							if(hold == 1) sReport.ui8Buttons |= 0x4;
							else sReport.ui8Buttons &= ~0x4;
						}
					
            //	***	Onboard Button Instance	***	//
            ButtonsPoll(&ui8ButtonsChanged, &ui8Buttons);
            if(ui8Buttons & RIGHT_BUTTON) sReport.ui8Buttons |= 0x80;
            if(ui8Buttons & LEFT_BUTTON) sReport.ui8Buttons |= 0x80;
            if(ui8ButtonsChanged) bUpdate = true;

            // Send the report if there was an update.						
            if(bUpdate && !PCB){	
                USBDHIDGamepadSendReport(&g_sGamepadDevice, &sReport, sizeof(sReport));
                IntMasterDisable();
                g_iGamepadState = eStateSending;	//sending data (protected from interrupts)
                IntMasterEnable();
                if(g_ui32Updates++ == 40){	//Blink rate of the LED.
                    ROM_GPIOPinWrite(GPIO_PORTF_BASE, GPIO_PIN_2, GPIO_PIN_2);// Turn on the blue LED.
                    g_ui32Updates = 0;	// Reset the update count.
                }
            }
        }
    }
}

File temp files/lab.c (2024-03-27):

/**
 * @file        lab.c
 * @author      your name (your_email@doman.com), Jonathan Valvano, Matthew Yu
 *              <TA NAME and LAB SECTION # HERE>
 * @brief       An empty main file for running your lab.
 * @version     0.1.0
 * @date        2022-10-08 <REPLACE WITH DATE OF LAST REVISION>
 * @copyright   Copyright (c) 2022
 * @note        Potential Pinouts:
 *                  Backlight (pin 10) connected to +3.3 V
 *                  MISO (pin 9) unconnected
 *                  SCK (pin 8) connected to PA2 (SSI0Clk)
 *                  MOSI (pin 7) connected to PA5 (SSI0Tx)
 *                  TFT_CS (pin 6) connected to PA3 (SSI0Fss)
 *                  CARD_CS (pin 5) unconnected
 *                  Data/Command (pin 4) connected to PA6 (GPIO)
 *                  RESET (pin 3) connected to PA7 (GPIO)
 *                  VCC (pin 2) connected to +3.3 V
 *                  Gnd (pin 1) connected to ground
 *
 *                  Center of 10k-ohm potentiometer connected to PE2/AIN1
 *                  Bottom of 10k-ohm potentiometer connected to ground
 *                  Top of 10k-ohm potentiometer connected to +3.3V
 *
 *              Warning. Initial code for the RGB driver creates bright flashing
 *              lights. Remove this code and do not run if you have epilepsy.
 */

/** File includes. */
#include <stdint.h>

/* Register definitions. */
#include "../inc/tm4c123gh6pm.h"
/* Clocking. */
#include "../inc/PLL.h"
/* Clock delay and interrupt control. */
#include "../inc/CortexM.h"
/* Initialization of all the pins. */
#include "../inc/Unified_Port_Init.h"
/* Talking to PC via UART. */
#include "../inc/UART.h"
/* ST7735 display. */
#include "../inc/ST7735.h"

/* Add whatever else you need here! */
#include "../lib/RGB/RGB.h"
#include "gyro.h"

int main(void) {
    /* Disable interrupts for initialization. */
    DisableInterrupts();

    /* Initialize clocking. */
    PLL_Init(Bus80Mhz);

    /* Allow us to talk to the PC via PuTTy! Check device manager to see which
       COM serial port we are on. The baud rate is 115200 chars/s. */
    UART_Init(7);

    /* Initialize all ports. */
    Unified_Port_Init();

    /* Start RGB flashing. WARNING! BRIGHT FLASHING COLORS. DO NOT RUN IF YOU HAVE EPILEPSY. */
    RGBInit();

    /* Allows any enabled timers to begin running. */
    EnableInterrupts();

    /* Print starting message to the PC and the ST7735. */
    ST7735_FillScreen(ST7735_BLACK);
    ST7735_SetCursor(0, 0);
    ST7735_OutString(
        "ECE445L Final lab.\n"
        "Press SW1 to start.\n");
    UART_OutString(
        "ECE445L Final lab.\r\n"
        "Press SW1 to start.\r\n");
    Pause();

    /* Stop RGB and turn off any on LEDs. */
    RGBStop();
    PF1 = 0;
    PF2 = 0;
    PF3 = 0;

    /* Reset screen. */
    ST7735_FillScreen(ST7735_BLACK);
    ST7735_SetCursor(0, 0);
    ST7735_OutString("Starting...\n");
    UART_OutString("Starting...\r\n");

		float gvalues[6];

    while (1) {
        /* TODO: Write your code here! */
        WaitForInterrupt();
				
				//read gyro data  --  can move to interrupts later
				gvalues = gyromain();
			
				//call usb/uart handlers after having read data
				//USB();
				//UART();
    }
    return 1;
}

/** Function Implementations. */
void DelayWait10ms(uint32_t n) {
    uint32_t volatile time;
    while (n){
        time = 727240 * 2 / 91;  // 10msec
        while (time){
            --time;
        }
        --n;
    }
}

void Pause(void) {
    while (PF4 == 0x00) {
        DelayWait10ms(10);
    }
    while (PF4 == 0x10) {
        DelayWait10ms(10);
    }
}

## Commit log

2024-03-20 boom boom
    [BOM.xlsx]
2024-03-23 created project for lab 7, 8, and 11
    [lab7811_project.kicad_pcb, lab7811_project.kicad_sch]
2024-03-23 Found some files to help with UART to USB communication
2024-03-25 gyro fix
2024-03-25 gyro trim
2024-03-25 docs fixed
    [BOM.xlsx]
2024-03-25 gyro issues
2024-03-27 gyro wip
2024-03-27 new footprints
2024-03-27 updated the schematic
    [lab7811_project.kicad_pcb]
2024-03-29 finished schematic and pcb for TA review
    [lab7811_project.kicad_pcb, lab7811_project.kicad_sch]
2024-03-29 bom and report updated
    [BOM.xlsx]
2024-03-29 gyro is stuck in a busy wait loop
    [gyro.c]
2024-04-01 approved pcb
    [cjh4858_gam3769_project.kicad_pcb, cjh4858_gam3769_project.kicad_sch]
2024-04-12 added wheel stl files in hw directory
    [garf_wheel_v1.stl, garf_wheel_v2.stl]
2024-04-12 fixed button bug
2024-04-12 defined button layout and control scheme
2024-04-17 visualization, new button config, menu
2024-04-17 button polling
2024-04-18 buttons fixed, holy shit so many errors
    [Unified_Port_Init.c, garf_handler.c, garf_wheel.c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]
2024-04-20 added the gyro stuff
2024-04-22 button fix
2024-04-25 GARFIELD WHEEL
    [garf_wheel_v3.stl, garf_wheel_v4.stl]
